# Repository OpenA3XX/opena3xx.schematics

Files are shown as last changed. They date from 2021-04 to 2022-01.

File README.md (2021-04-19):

# OpenA3XX Schematics & PCBs

## OpenA3XX Digital Hardare Controller Board (HCB)
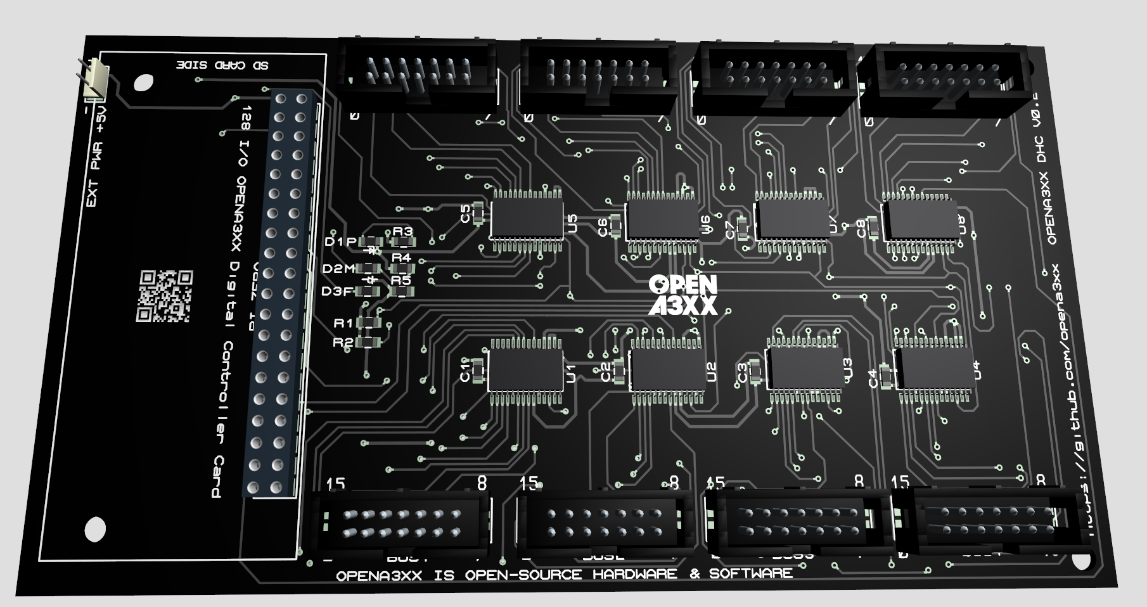
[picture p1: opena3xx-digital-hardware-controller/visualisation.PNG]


## OpenA3XX MCDU with embedded HCB (Optional)
### Front View
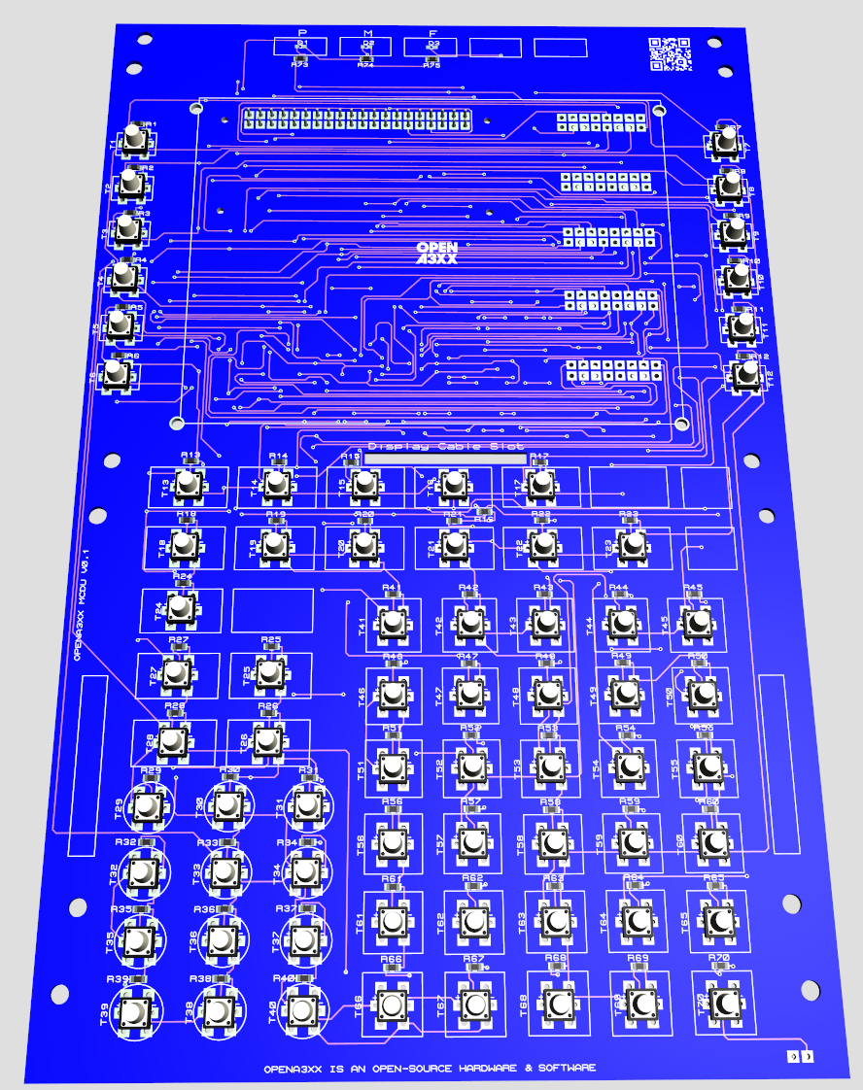
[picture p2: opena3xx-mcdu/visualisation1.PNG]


### Back View
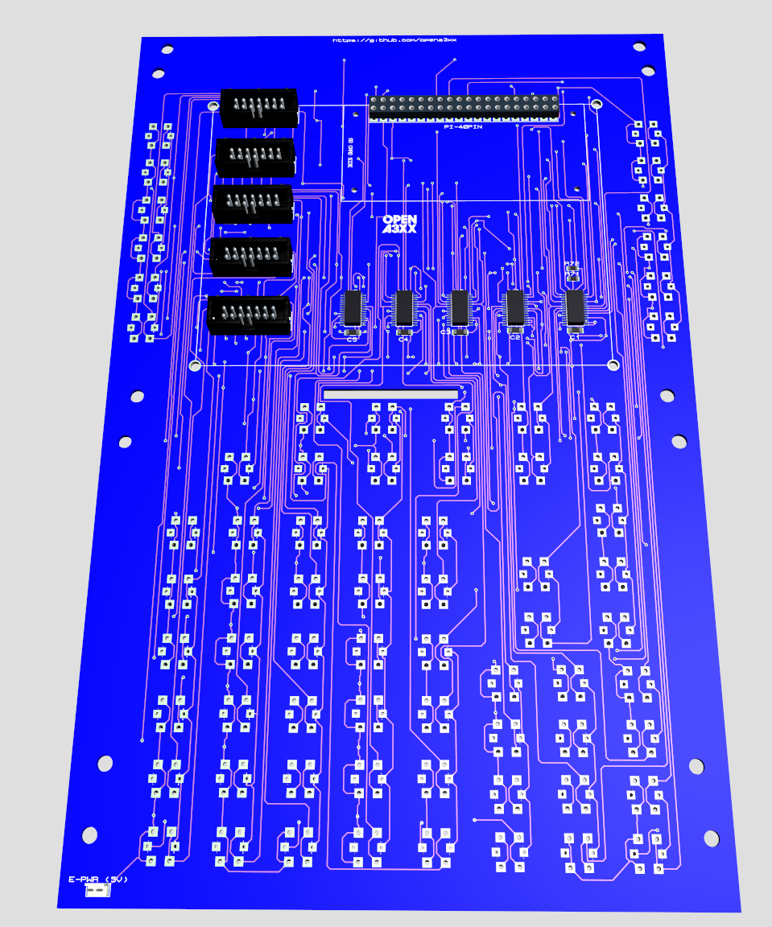
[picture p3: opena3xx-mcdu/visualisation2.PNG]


## OpenA3XX IO Terminal Block Boards

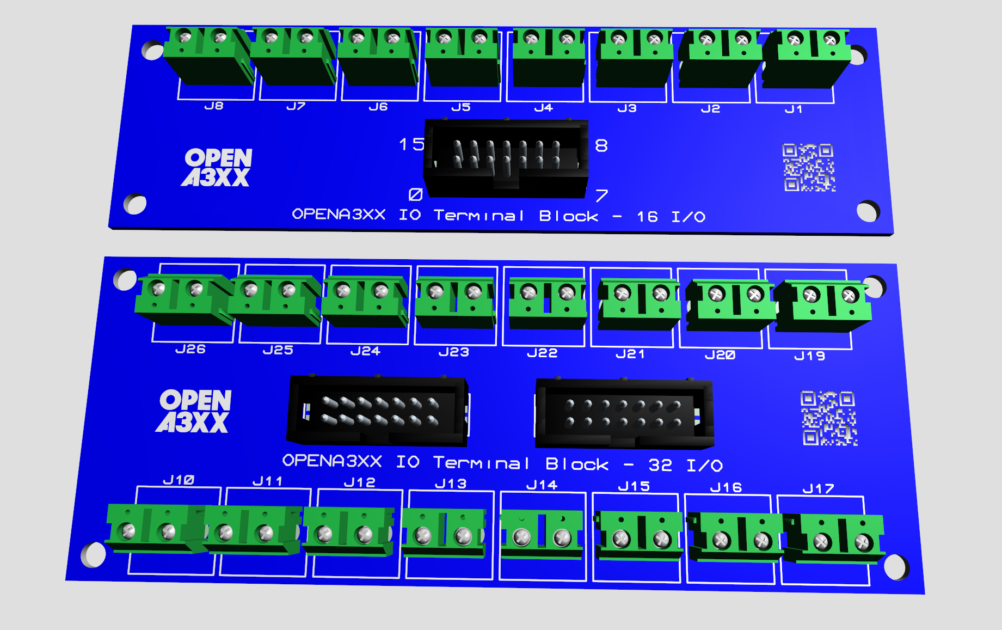
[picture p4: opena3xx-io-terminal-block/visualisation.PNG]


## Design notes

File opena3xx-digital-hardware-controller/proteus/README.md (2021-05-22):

## OpenA3XX Digital Hardware Controller Board

## Design Tools

To open schematics and pcb designs install kicad. Based on your operating system follow the guid here.
[Setup/Download Here](https://www.kicad.org/)

## Versions
- 0.1 (Implemented using Proteus by Labcentre Electronics)
- 0.2 (Implemented using Proteus by Labcentre Electronics)
- 0.3 (Implemented using Proteus by Labcentre Electronics)
- 0.4 (Implemented using Kicad - Open Source)

## Recommendations

For all passive SMD Components it's recommended that you will buy assorted of all values from Aliexpress.
All designs will use footprints which are easy for hand soldering i.e. 1206 package type.
For ICs SOIC packages are used for the same reasons.

## Bill of Material

|Reference|Value |Footprint |Datasheet |
|---|---|---|---|
|U1 |MCP23017_SO |Package_SO:SOIC-28W_7.5x17.9mm_P1.27mm |http://ww1.microchip.com/downloads/en/DeviceDoc/20001952C.pdf |
|BUS0 |Conn_02x08_Counter_Clockwise|Connector_PinHeader_2.54mm:PinHeader_2x08_P2.54mm_Vertical|~ |
|BUS1 |Conn_02x08_Counter_Clockwise|Connector_PinHeader_2.54mm:PinHeader_2x08_P2.54mm_Vertical|~ |
|U2 |MCP23017_SO |Package_SO:SOIC-28W_7.5x17.9mm_P1.27mm |http://ww1.microchip.com/downloads/en/DeviceDoc/20001952C.pdf |
|BUS2 |Conn_02x08_Counter_Clockwise|Connector_PinHeader_2.54mm:PinHeader_2x08_P2.54mm_Vertical|~ |
|U3 |MCP23017_SO |Package_SO:SOIC-28W_7.5x17.9mm_P1.27mm |http://ww1.microchip.com/downloads/en/DeviceDoc/20001952C.pdf |
|J5 |Raspberry_Pi_Zero |Connector_PinHeader_2.54mm:PinHeader_2x20_P2.54mm_Vertical|https://www.raspberrypi.org/documentation/hardware/raspberrypi/schematics/rpi_SCH_3bplus_1p0_reduced.pdf|
|BUS3 |Conn_02x08_Counter_Clockwise|Connector_PinHeader_2.54mm:PinHeader_2x08_P2.54mm_Vertical|~ |
|U4 |MCP23017_SO |Package_SO:SOIC-28W_7.5x17.9mm_P1.27mm |http://ww1.microchip.com/downloads/en/DeviceDoc/20001952C.pdf |
|BUS4 |Conn_02x08_Counter_Clockwise|Connector_PinHeader_2.54mm:PinHeader_2x08_P2.54mm_Vertical|~ |
|U5 |MCP23017_SO |Package_SO:SOIC-28W_7.5x17.9mm_P1.27mm |http://ww1.microchip.com/downloads/en/DeviceDoc/20001952C.pdf |
|BUS5 |Conn_02x08_Counter_Clockwise|Connector_PinHeader_2.54mm:PinHeader_2x08_P2.54mm_Vertical|~ |
|U6 |MCP23017_SO |Package_SO:SOIC-28W_7.5x17.9mm_P1.27mm |http://ww1.microchip.com/downloads/en/DeviceDoc/20001952C.pdf |
|BUS6 |Conn_02x08_Counter_Clockwise|Connector_PinHeader_2.54mm:PinHeader_2x08_P2.54mm_Vertical|~ |
|U7 |MCP23017_SO |Package_SO:SOIC-28W_7.5x17.9mm_P1.27mm |http://ww1.microchip.com/downloads/en/DeviceDoc/20001952C.pdf |
|BUS7 |Conn_02x08_Counter_Clockwise|Connector_PinHeader_2.54mm:PinHeader_2x08_P2.54mm_Vertical|~ |
|U8 |MCP23017_SO |Package_SO:SOIC-28W_7.5x17.9mm_P1.27mm |http://ww1.microchip.com/downloads/en/DeviceDoc/20001952C.pdf |
|D1 |GREEN LED |Diode_SMD:D_1206_3216Metric_Pad1.42x1.75mm_HandSolder |~ |
|R1 |470R |Resistor_SMD:R_1206_3216Metric_Pad1.30x1.75mm_HandSolder  |~ |
|R2 |470R |Resistor_SMD:R_1206_3216Metric_Pad1.30x1.75mm_HandSolder  |~ |
|D3 |RED LED |Diode_SMD:D_1206_3216Metric_Pad1.42x1.75mm_HandSolder |~ |
|R3 |470R |Resistor_SMD:R_1206_3216Metric_Pad1.30x1.75mm_HandSolder  |~ |
|R4 |470R |Resistor_SMD:R_1206_3216Metric_Pad1.30x1.75mm_HandSolder  |~ |
|D4 |ORANGE LED |Diode_SMD:D_1206_3216Metric_Pad1.42x1.75mm_HandSolder |~ |
|D2 |YELLOW LED |Diode_SMD:D_1206_3216Metric_Pad1.42x1.75mm_HandSolder |~ |
|R13 |2.2k |Resistor_SMD:R_1206_3216Metric_Pad1.30x1.75mm_HandSolder  |~ |
|R14 |2.2k |Resistor_SMD:R_1206_3216Metric_Pad1.30x1.75mm_HandSolder  |~ |
|C1 |100n |Capacitor_SMD:C_1206_3216Metric_Pad1.33x1.80mm_HandSolder |~ |
|C2 |100n |Capacitor_SMD:C_1206_3216Metric_Pad1.33x1.80mm_HandSolder |~ |
|C3 |100n |Capacitor_SMD:C_1206_3216Metric_Pad1.33x1.80mm_HandSolder |~ |
|C4 |100n |Capacitor_SMD:C_1206_3216Metric_Pad1.33x1.80mm_HandSolder |~ |
|C5 |100n |Capacitor_SMD:C_1206_3216Metric_Pad1.33x1.80mm_HandSolder |~ |
|C6 |100n |Capacitor_SMD:C_1206_3216Metric_Pad1.33x1.80mm_HandSolder |~ |
|C7 |100n |Capacitor_SMD:C_1206_3216Metric_Pad1.33x1.80mm_HandSolder |~ |
|C8 |100n |Capacitor_SMD:C_1206_3216Metric_Pad1.33x1.80mm_HandSolder |~ |
|R6 |10k |Resistor_SMD:R_1206_3216Metric_Pad1.30x1.75mm_HandSolder  |~ |
|R5 |10k |Resistor_SMD:R_1206_3216Metric_Pad1.30x1.75mm_HandSolder  |~ |
|R7 |10k |Resistor_SMD:R_1206_3216Metric_Pad1.30x1.75mm_HandSolder  |~ |
|R8 |10k |Resistor_SMD:R_1206_3216Metric_Pad1.30x1.75mm_HandSolder  |~ |
|R9 |10k |Resistor_SMD:R_1206_3216Metric_Pad1.30x1.75mm_HandSolder  |~ |
|R10 |10k |Resistor_SMD:R_1206_3216Metric_Pad1.30x1.75mm_HandSolder  |~ |
|R11 |10k |Resistor_SMD:R_1206_3216Metric_Pad1.30x1.75mm_HandSolder  |~ |
|R12 |10k |Resistor_SMD:R_1206_3216Metric_Pad1.30x1.75mm_HandSolder  |~ |
|J1 |Conn_02x01 |Connector_PinHeader_2.54mm:PinHeader_1x02_P2.54mm_Vertical|~ |
|J2 |Conn_02x01 |Connector_PinHeader_2.54mm:PinHeader_1x02_P2.54mm_Vertical|~ |
|J3 |Conn_02x01 |TerminalBlock:TerminalBlock_bornier-2_P5.08mm |~ |
|J4 |Conn_02x01 |TerminalBlock:TerminalBlock_bornier-2_P5.08mm |~ |
|SW1 |SW_MEC_5E |Button_Switch_THT:SW_Tactile_Straight_KSL0Axx1LFTR |http://www.apem.com/int/index.php?controller=attachment&id_attachment=1371 |
|R15 |2.2k |Resistor_SMD:R_1206_3216Metric_Pad1.30x1.75mm_HandSolder  |~ |

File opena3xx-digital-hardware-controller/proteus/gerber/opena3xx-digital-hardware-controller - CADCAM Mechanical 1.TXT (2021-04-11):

G04 PROTEUS RS274X GERBER FILE*
%FSLAX24Y24*%
%MOIN*%
%ADD15C,0.0080*%
G54D15*
X-50787Y+29527D02*
X-16535Y+29527D01*
X-16535Y+48031D01*
X-50787Y+48031D01*
X-50787Y+29527D01*
M00*

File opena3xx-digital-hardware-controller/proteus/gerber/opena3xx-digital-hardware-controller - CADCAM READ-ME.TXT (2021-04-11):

LABCENTER PROTEUS TOOL INFORMATION FILE
=======================================

In case of difficulty, please e-mail support@labcenter.co.uk

Tool set up for Proteus layout 'opena3xx-digital-hardware-controller.LYT'.
CADCAM generated at 22:12:48 on 10 April 2021.

File List
---------
Top Copper              : opena3xx-digital-hardware-controller - CADCAM Top Copper.TXT
Bottom Copper           : opena3xx-digital-hardware-controller - CADCAM Bottom Copper.TXT
Top Silk Screen         : opena3xx-digital-hardware-controller - CADCAM Top Silk Screen.TXT
Top Solder Resist       : opena3xx-digital-hardware-controller - CADCAM Top Solder Resist.TXT
Bottom Solder Resist    : opena3xx-digital-hardware-controller - CADCAM Bottom Solder Resist.TXT
Top SMT Paste Mask      : opena3xx-digital-hardware-controller - CADCAM Top SMT Paste Mask.TXT
Mechanical 1            : opena3xx-digital-hardware-controller - CADCAM Mechanical 1.TXT
Drill                   : opena3xx-digital-hardware-controller - CADCAM Drill.TXT

Photoplotter Setup
------------------
Format: RS274X, ASCII, 2.4, imperial, absolute, eob=*, LZO
Notes:  D=Diameter, S=Side, W=Width, H=Height, C=Chamfer

D10	CIRCLE  D=10th                                                            DRAW
D11	CIRCLE  D=30th                                                            FLASH
D12	SQUARE  S=80th                                                            FLASH
D13	RECT    W=39.3th              H=11.8th                                    FLASH
D14	RECT    W=40th                H=50th                                      FLASH
D15	CIRCLE  D=8th                                                             DRAW
D16	CIRCLE  D=50th                                                            FLASH
D17	SQUARE  S=100th                                                           FLASH
D18	RECT    W=59.3th              H=31.8th                                    FLASH
D19	RECT    W=60th                H=70th                                      FLASH

NC Drill Setup
--------------
Format: ASCII, 2.4, imperial, absolute, eob=<CR><LF>, no zero suppression.
Notes:  Tool sizes are diameters. Layer sets are in brackets - 0=TOP, 15=BOTTOM, 1-14=INNER.

T01	15th (0-15)
T02	40th (0-15)
T03	30th (0-15)

[END OF FILE]

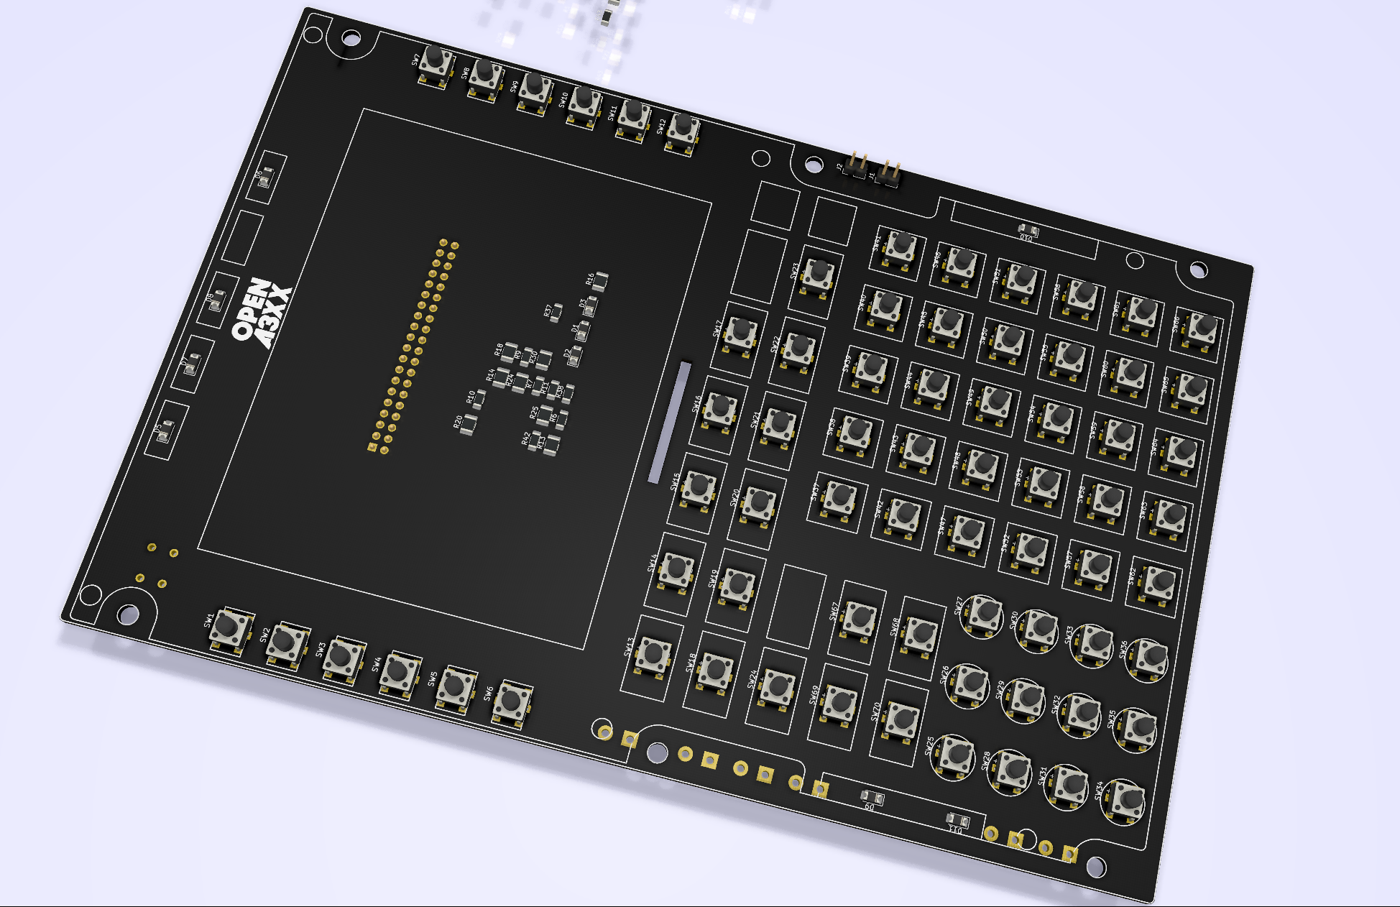
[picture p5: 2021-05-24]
opena3xx-mcdu/proteus/MCDU_Render3.png

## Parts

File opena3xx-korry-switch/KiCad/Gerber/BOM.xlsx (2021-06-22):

Comment | Designator | Footprint | LCSC Part #（optional）
270 | R1 | R_1206_3216Metric
270 | R2 | R_1206_3216Metric
1x5 2.54mm Vertical | CON1 | Conn_01x05_MountingPin

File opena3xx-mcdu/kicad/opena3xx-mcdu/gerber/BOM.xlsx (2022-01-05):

Comment | Designator | Footprint | LCSC Part #（optional）
Terminal Block | J1 | Conn_02x01_TerminalBlock | C8404
Terminal Block | J2 | Conn_02x01_TerminalBlock | C8404
Terminal Block | J3 | Conn_02x01_TerminalBlock | C8404
Terminal Block | J4 | Conn_02x01_TerminalBlock | C8404
Terminal Block | J6 | Conn_02x01_TerminalBlock | C8404
Terminal Block | J7 | Conn_02x01_TerminalBlock | C8404
Terminal Block | J8 | Conn_02x01_TerminalBlock | C8404
Terminal Block | J9 | Conn_02x01_TerminalBlock | C8404
Tactile Switch with LED | SW1 | TLL-6A_TACTILE_LED_TH | C354965
Tactile Switch with LED | SW2 | TLL-6A_TACTILE_LED_TH | C354965
Tactile Switch with LED | SW3 | TLL-6A_TACTILE_LED_TH | C354965
Tactile Switch with LED | SW4 | TLL-6A_TACTILE_LED_TH | C354965
Tactile Switch with LED | SW5 | TLL-6A_TACTILE_LED_TH | C354965
Tactile Switch with LED | SW6 | TLL-6A_TACTILE_LED_TH | C354965
Tactile Switch with LED | SW7 | TLL-6A_TACTILE_LED_TH | C354965
Tactile Switch with LED | SW8 | TLL-6A_TACTILE_LED_TH | C354965
Tactile Switch with LED | SW9 | TLL-6A_TACTILE_LED_TH | C354965
Tactile Switch with LED | SW10 | TLL-6A_TACTILE_LED_TH | C354965
Tactile Switch with LED | SW11 | TLL-6A_TACTILE_LED_TH | C354965
Tactile Switch with LED | SW12 | TLL-6A_TACTILE_LED_TH | C354965
Tactile Switch with LED | SW13 | TLL-6A_TACTILE_LED_TH | C354965
Tactile Switch with LED | SW14 | TLL-6A_TACTILE_LED_TH | C354965
Tactile Switch with LED | SW15 | TLL-6A_TACTILE_LED_TH | C354965
Tactile Switch with LED | SW16 | TLL-6A_TACTILE_LED_TH | C354965
Tactile Switch with LED | SW17 | TLL-6A_TACTILE_LED_TH | C354965
Tactile Switch with LED | SW18 | TLL-6A_TACTILE_LED_TH | C354965
Tactile Switch with LED | SW19 | TLL-6A_TACTILE_LED_TH | C354965
Tactile Switch with LED | SW20 | TLL-6A_TACTILE_LED_TH | C354965
Tactile Switch with LED | SW21 | TLL-6A_TACTILE_LED_TH | C354965
Tactile Switch with LED | SW22 | TLL-6A_TACTILE_LED_TH | C354965
Tactile Switch with LED | SW23 | TLL-6A_TACTILE_LED_TH | C354965
Tactile Switch with LED | SW24 | TLL-6A_TACTILE_LED_TH | C354965
Tactile Switch with LED | SW25 | TLL-6A_TACTILE_LED_TH | C354965
Tactile Switch with LED | SW26 | TLL-6A_TACTILE_LED_TH | C354965
Tactile Switch with LED | SW27 | TLL-6A_TACTILE_LED_TH | C354965
Tactile Switch with LED | SW28 | TLL-6A_TACTILE_LED_TH | C354965
Tactile Switch with LED | SW29 | TLL-6A_TACTILE_LED_TH | C354965
Tactile Switch with LED | SW30 | TLL-6A_TACTILE_LED_TH | C354965
Tactile Switch with LED | SW31 | TLL-6A_TACTILE_LED_TH | C354965
Tactile Switch with LED | SW32 | TLL-6A_TACTILE_LED_TH | C354965
Tactile Switch with LED | SW33 | TLL-6A_TACTILE_LED_TH | C354965
Tactile Switch with LED | SW34 | TLL-6A_TACTILE_LED_TH | C354965
Tactile Switch with LED | SW35 | TLL-6A_TACTILE_LED_TH | C354965
Tactile Switch with LED | SW36 | TLL-6A_TACTILE_LED_TH | C354965
Tactile Switch with LED | SW37 | TLL-6A_TACTILE_LED_TH | C354965
Tactile Switch with LED | SW38 | TLL-6A_TACTILE_LED_TH | C354965
Tactile Switch with LED | SW39 | TLL-6A_TACTILE_LED_TH | C354965
Tactile Switch with LED | SW40 | TLL-6A_TACTILE_LED_TH | C354965
Tactile Switch with LED | SW41 | TLL-6A_TACTILE_LED_TH | C354965
Tactile Switch with LED | SW42 | TLL-6A_TACTILE_LED_TH | C354965
Tactile Switch with LED | SW43 | TLL-6A_TACTILE_LED_TH | C354965
Tactile Switch with LED | SW44 | TLL-6A_TACTILE_LED_TH | C354965
Tactile Switch with LED | SW45 | TLL-6A_TACTILE_LED_TH | C354965
Tactile Switch with LED | SW46 | TLL-6A_TACTILE_LED_TH | C354965
Tactile Switch with LED | SW47 | TLL-6A_TACTILE_LED_TH | C354965
Tactile Switch with LED | SW48 | TLL-6A_TACTILE_LED_TH | C354965
Tactile Switch with LED | SW49 | TLL-6A_TACTILE_LED_TH | C354965
Tactile Switch with LED | SW50 | TLL-6A_TACTILE_LED_TH | C354965
Tactile Switch with LED | SW51 | TLL-6A_TACTILE_LED_TH | C354965
Tactile Switch with LED | SW52 | TLL-6A_TACTILE_LED_TH | C354965
Tactile Switch with LED | SW53 | TLL-6A_TACTILE_LED_TH | C354965
Tactile Switch with LED | SW54 | TLL-6A_TACTILE_LED_TH | C354965
Tactile Switch with LED | SW55 | TLL-6A_TACTILE_LED_TH | C354965
Tactile Switch with LED | SW56 | TLL-6A_TACTILE_LED_TH | C354965
Tactile Switch with LED | SW57 | TLL-6A_TACTILE_LED_TH | C354965
Tactile Switch with LED | SW58 | TLL-6A_TACTILE_LED_TH | C354965
Tactile Switch with LED | SW59 | TLL-6A_TACTILE_LED_TH | C354965
Tactile Switch with LED | SW60 | TLL-6A_TACTILE_LED_TH | C354965
Tactile Switch with LED | SW61 | TLL-6A_TACTILE_LED_TH | C354965
Tactile Switch with LED | SW62 | TLL-6A_TACTILE_LED_TH | C354965
Tactile Switch with LED | SW63 | TLL-6A_TACTILE_LED_TH | C354965
Tactile Switch with LED | SW64 | TLL-6A_TACTILE_LED_TH | C354965
Tactile Switch with LED | SW65 | TLL-6A_TACTILE_LED_TH | C354965
Tactile Switch with LED | SW66 | TLL-6A_TACTILE_LED_TH | C354965
Tactile Switch with LED | SW67 | TLL-6A_TACTILE_LED_TH | C354965
Tactile Switch with LED | SW68 | TLL-6A_TACTILE_LED_TH | C354965
Tactile Switch with LED | SW69 | TLL-6A_TACTILE_LED_TH | C354965
Tactile Switch with LED | SW70 | TLL-6A_TACTILE_LED_TH | C354965
Tactile Switch with LED | SW71 | TLL-6A_TACTILE_LED_TH | C354965
Tactile Switch with LED | SW72 | TLL-6A_TACTILE_LED_TH | C354965
Tactile Switch with LED | SW73 | TLL-6A_TACTILE_LED_TH | C354965
Tactile Switch with LED | SW74 | TLL-6A_TACTILE_LED_TH | C354965
220R | R13 | R_1210_3225Metric | C17957
220R | R14 | R_1210_3225Metric | C17957
220R | R15 | R_1210_3225Metric | C17957
220R | R16 | R_1210_3225Metric | C17957
220R | R17 | R_1210_3225Metric | C17957
220R | R18 | R_1210_3225Metric | C17957
220R | R19 | R_1210_3225Metric | C17957
220R | R20 | R_1210_3225Metric | C17957
220R | R21 | R_1210_3225Metric | C17957
220R | R22 | R_1210_3225Metric | C17957
220R | R23 | R_1210_3225Metric | C17957
220R | R24 | R_1210_3225Metric | C17957
220R | R25 | R_1210_3225Metric | C17957
220R | R26 | R_1210_3225Metric | C17957
220R | R27 | R_1210_3225Metric | C17957
220R | R28 | R_1210_3225Metric | C17957
220R | R29 | R_1210_3225Metric | C17957
220R | R30 | R_1210_3225Metric | C17957
220R | R31 | R_1210_3225Metric | C17957
220R | R32 | R_1210_3225Metric | C17957
220R | R33 | R_1210_3225Metric | C17957
220R | R34 | R_1210_3225Metric | C17957
220R | R35 | R_1210_3225Metric | C17957
220R | R44 | R_1210_3225Metric | C17957
MCP23017_SO | U1 | SOIC-28W | C47023
MCP23017_SO | U2 | SOIC-28W | C47023
MCP23017_SO | U3 | SOIC-28W | C47023
MCP23017_SO | U4 | SOIC-28W | C47023
MCP23017_SO | U5 | SOIC-28W | C47023
Tactile Switch MEC_5E | SW100 | SW_TH_Tactile_Omron_B3F-10xx | C111609
470R | R43 | R_1206_3216Metric | C4502
470R | R42 | R_1206_3216Metric | C4502
470R | R41 | R_1206_3216Metric | C4502
470R | R40 | R_1206_3216Metric | C4502
470R | R39 | R_1206_3216Metric | C4502
470R | R38 | R_1206_3216Metric | C4502
470R | R37 | R_1206_3216Metric | C4502
470R | R4 | R_1206_3216Metric | C4502
470R | R3 | R_1206_3216Metric | C4502
470R | R2 | R_1206_3216Metric | C4502
470R | R36 | R_1206_3216Metric | C4502
470R | R1 | R_1206_3216Metric | C4502
2.2K | R12 | R_1206_3216Metric | C17948
2.2K | R11 | R_1206_3216Metric | C17948
2.2K | R10 | R_1206_3216Metric | C17948
10K | R9 | R_1206_3216Metric | C17902
10K | R8 | R_1206_3216Metric | C17902
10K | R7 | R_1206_3216Metric | C17902
10K | R6 | R_1206_3216Metric | C17902
10K | R5 | R_1206_3216Metric | C17902
2x20 2.54mm Vertical | J5 | Conn_02x20_MountingPin | C124383
White LED | D11 | D_1206_3216Metric | C130718
White LED | D10 | D_1206_3216Metric | C130718
Amber LED | D9 | D_1206_3216Metric | C93094
Green LED | D8 | D_1206_3216Metric | C434439
Amber LED | D7 | D_1206_3216Metric | C93094
Amber LED | D6 | D_1206_3216Metric | C93094
Amber LED | D5 | D_1206_3216Metric | C93094
Orange LED | D4 | D_1206_3216Metric | C93094
Red LED | D3 | D_1206_3216Metric | C192674
Yellow LED | D2 | D_1206_3216Metric | C93094
Green LED | D1 | D_1206_3216Metric | C434439
100n Capacitor | C1 | C_1206_3216Metric | C24497
100n Capacitor | C2 | C_1206_3216Metric | C24497
100n Capacitor | C3 | C_1206_3216Metric | C24497
100n Capacitor | C4 | C_1206_3216Metric | C24497
100n Capacitor | C5 | C_1206_3216Metric | C24497
22.0K | R45 | R_1206_3216Metric | C25830
10.0K | R46 | R_1206_3216Metric | C17902
220R | R47 | R_1206_3216Metric | C17957

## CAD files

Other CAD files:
opena3xx-mcdu/proteus/1212D.dwg

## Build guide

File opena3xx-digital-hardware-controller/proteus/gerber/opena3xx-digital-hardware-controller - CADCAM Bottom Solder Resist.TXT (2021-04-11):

G04 PROTEUS RS274X GERBER FILE*
%FSLAX24Y24*%
%MOIN*%
%ADD16C,0.0500*%
%ADD17R,0.1000X0.1000*%
%ADD15C,0.0080*%
G54D16*
X-33250Y+34500D03*
X-46250Y+36000D03*
X-43000Y+35750D03*
X-41750Y+30500D03*
X-43000Y+35250D03*
X-44000Y+35250D03*
X-46250Y+31000D03*
X-33250Y+30500D03*
X-37500Y+30500D03*
X-48500Y+42750D03*
X-38750Y+31000D03*
X-32500Y+36500D03*
X-35250Y+32000D03*
X-41750Y+31000D03*
X-37500Y+36250D03*
X-46250Y+36500D03*
X-34250Y+35250D03*
X-40750Y+30250D03*
X-37000Y+31000D03*
X-30250Y+36250D03*
X-24750Y+39250D03*
X-23750Y+39500D03*
X-21750Y+40000D03*
X-19750Y+41000D03*
X-18750Y+42250D03*
X-31500Y+35750D03*
X-40500Y+35500D03*
X-41250Y+37250D03*
X-36500Y+30750D03*
X-47750Y+45000D03*
X-36500Y+37000D03*
X-31000Y+31000D03*
X-29750Y+31000D03*
X-31500Y+36750D03*
X-31500Y+36250D03*
X-41750Y+36500D03*
X-41750Y+34000D03*
G54D17*
X-46850Y+45669D03*
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

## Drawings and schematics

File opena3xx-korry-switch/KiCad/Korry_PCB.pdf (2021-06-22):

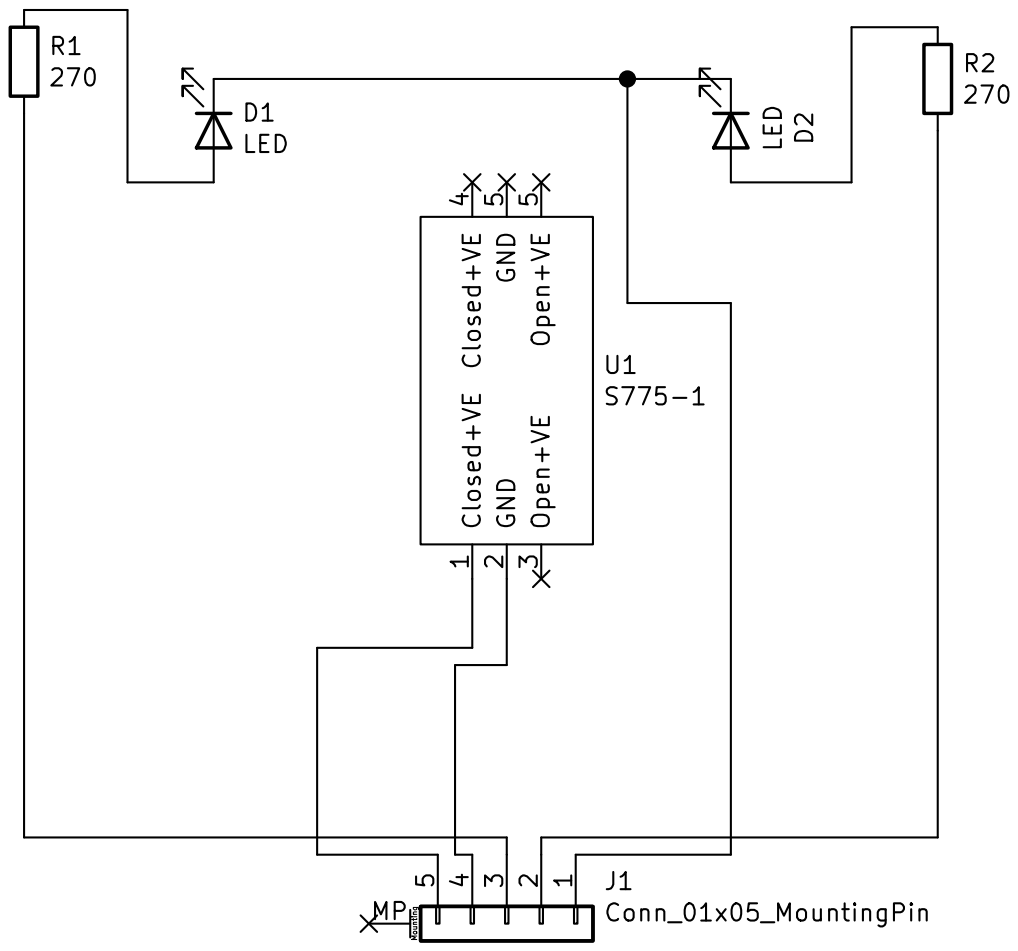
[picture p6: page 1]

Id: 1/1 Title: Korry Switch PCB

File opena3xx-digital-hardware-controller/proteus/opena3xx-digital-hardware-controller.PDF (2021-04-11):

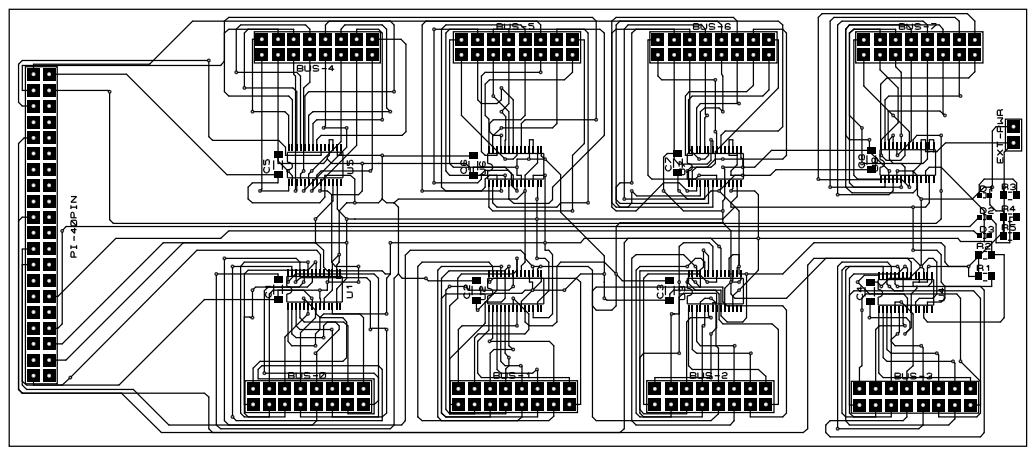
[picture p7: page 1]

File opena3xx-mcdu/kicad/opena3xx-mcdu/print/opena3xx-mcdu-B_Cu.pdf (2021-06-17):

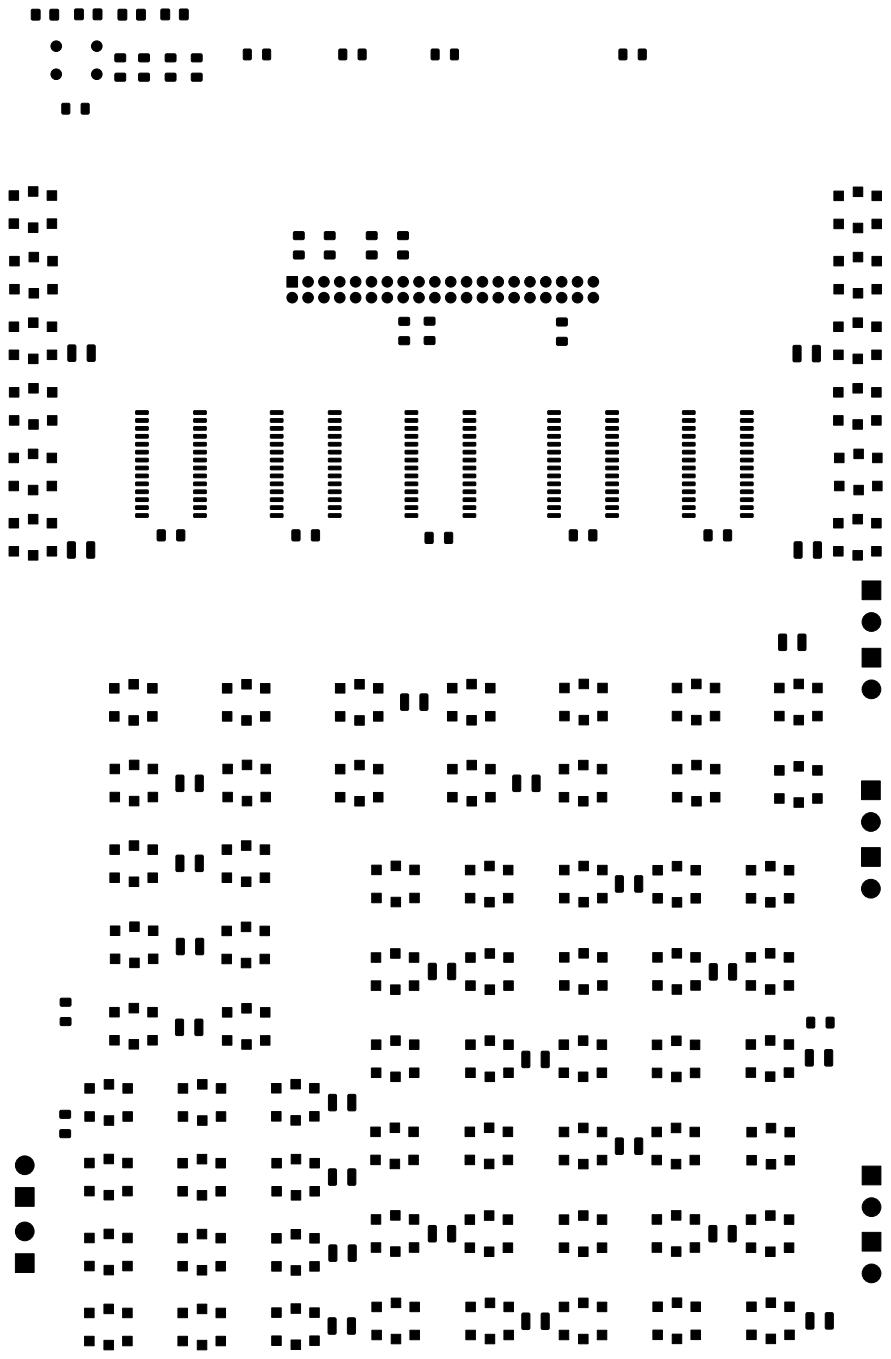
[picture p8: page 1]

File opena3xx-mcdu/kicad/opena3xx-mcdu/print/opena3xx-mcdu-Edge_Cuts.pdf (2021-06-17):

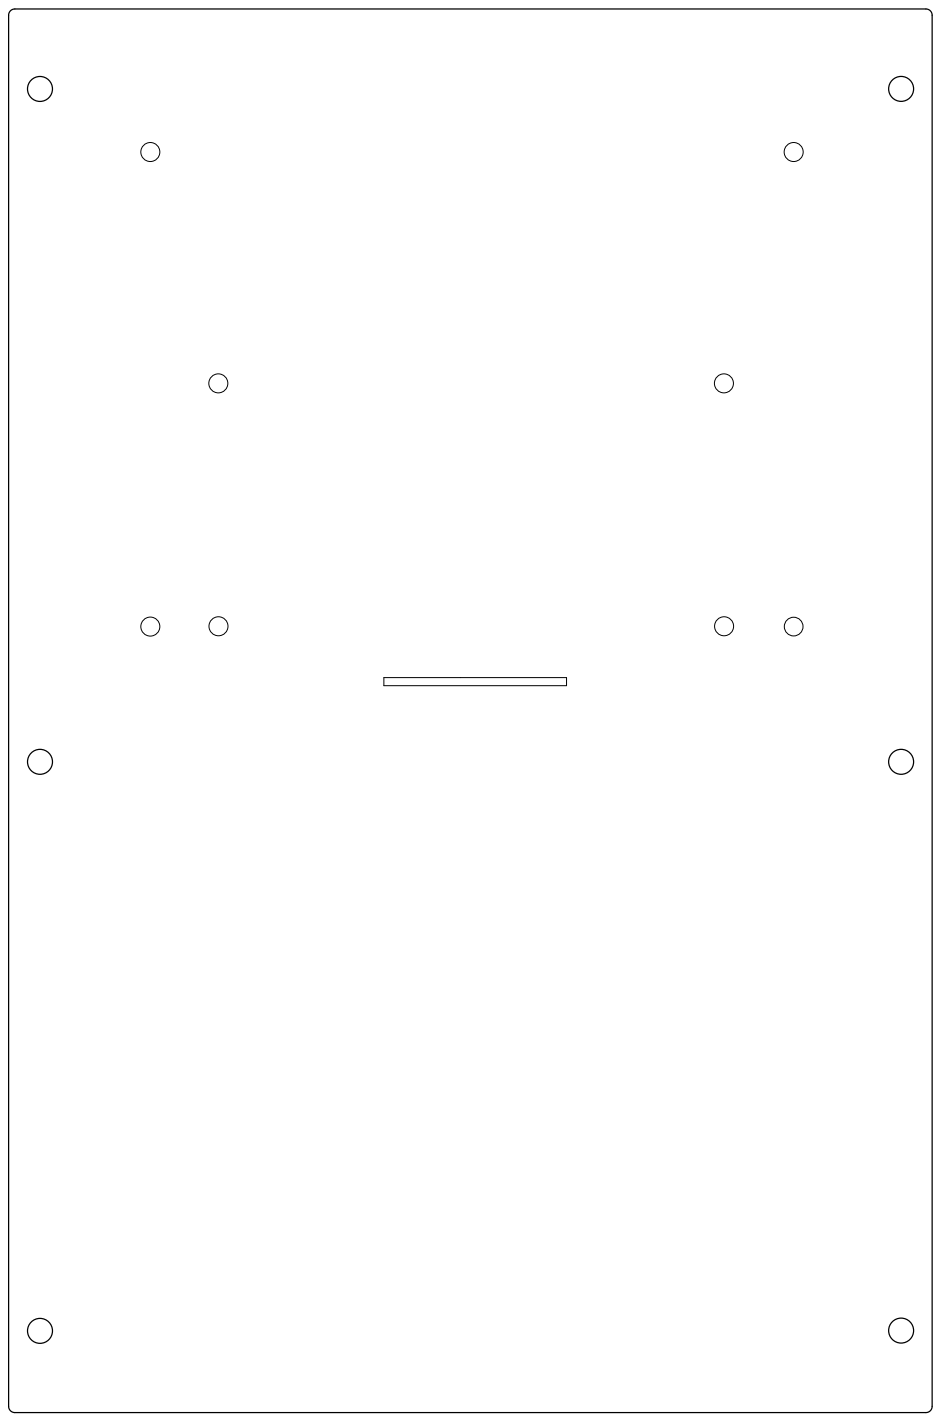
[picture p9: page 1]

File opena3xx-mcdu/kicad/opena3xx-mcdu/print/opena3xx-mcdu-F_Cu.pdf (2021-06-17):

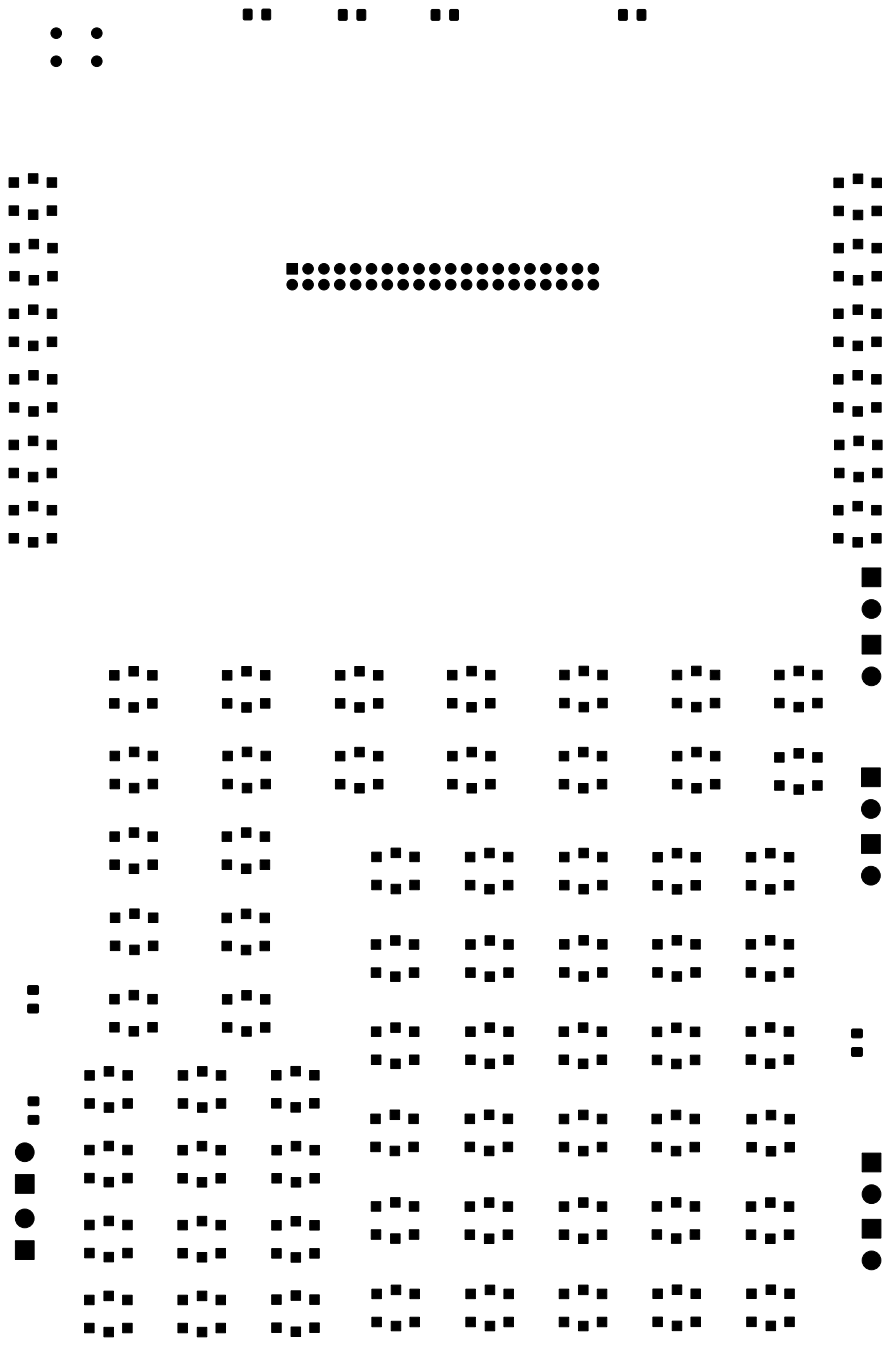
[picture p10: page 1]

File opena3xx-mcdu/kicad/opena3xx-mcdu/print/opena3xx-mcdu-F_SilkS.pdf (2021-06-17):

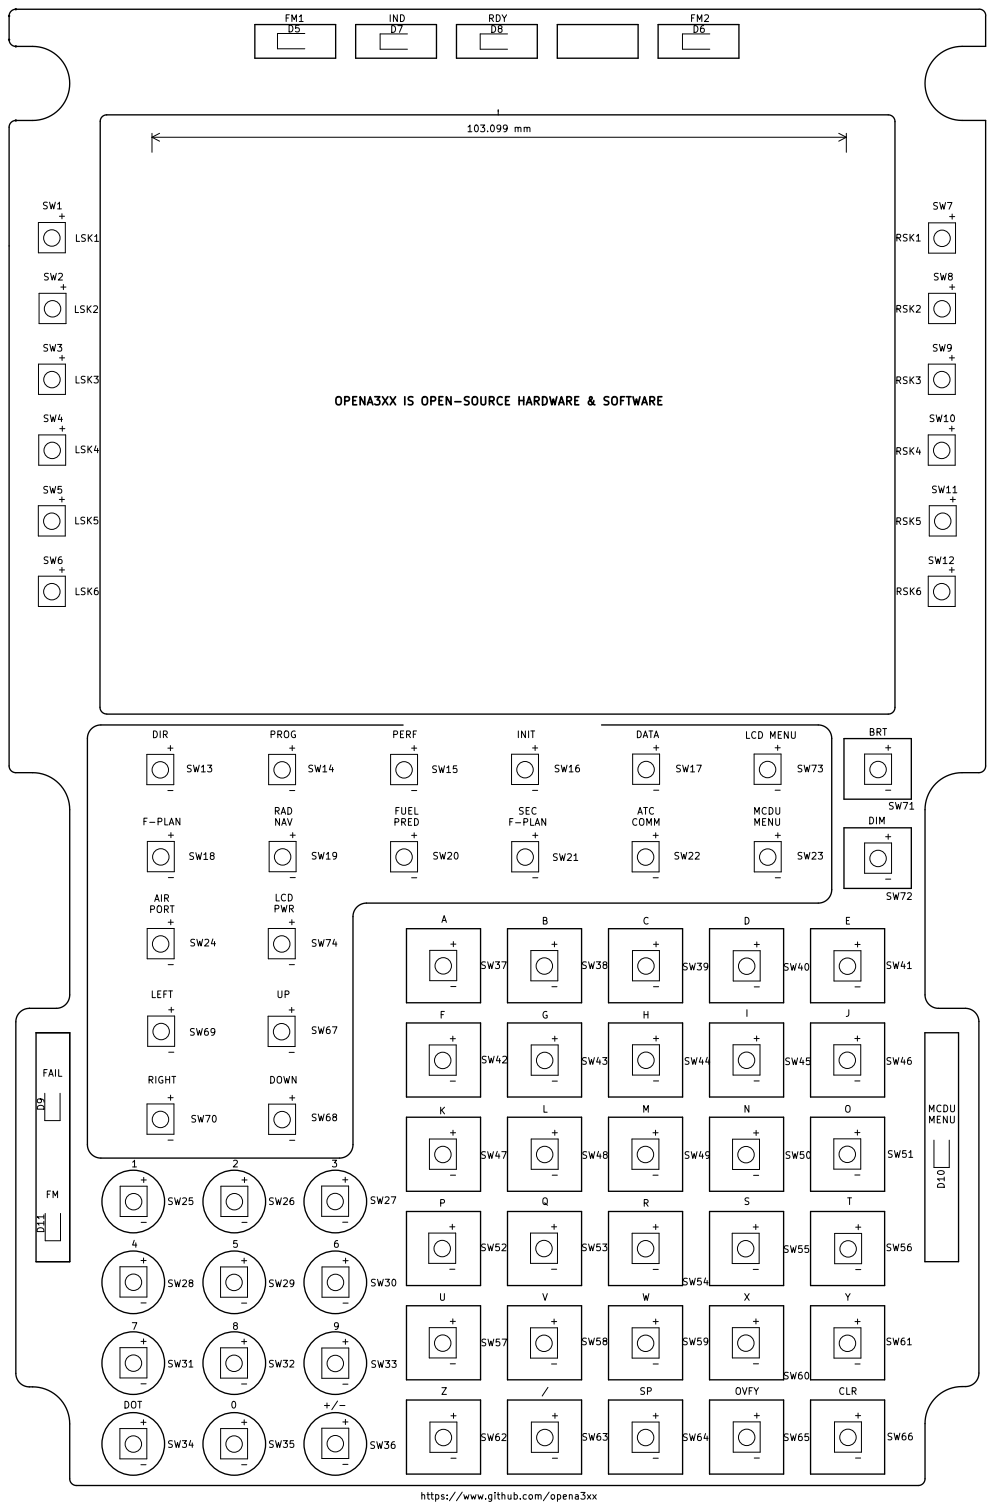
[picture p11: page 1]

https://www.github.com/opena3xx

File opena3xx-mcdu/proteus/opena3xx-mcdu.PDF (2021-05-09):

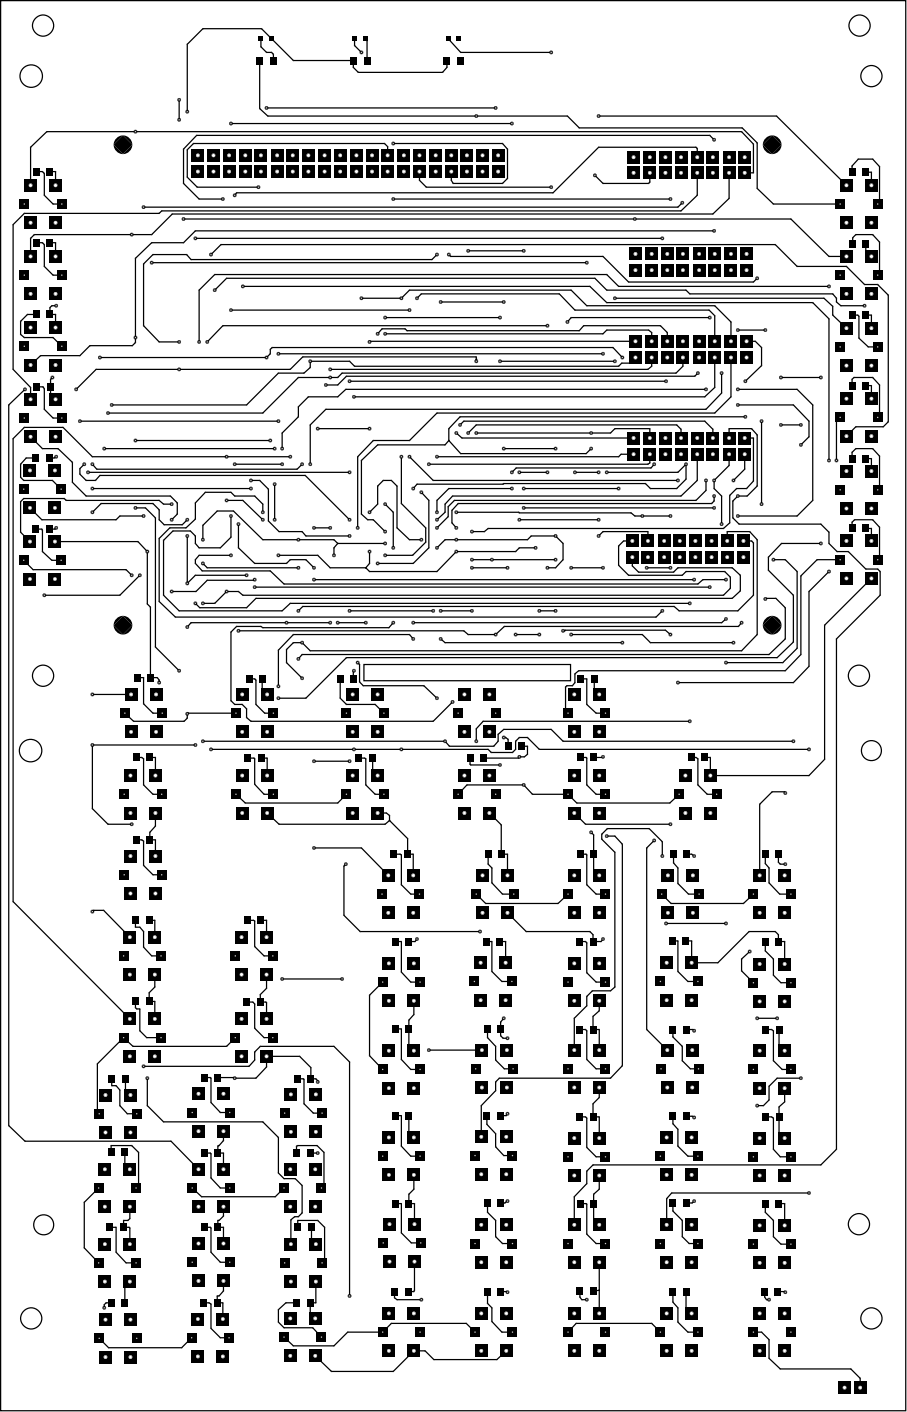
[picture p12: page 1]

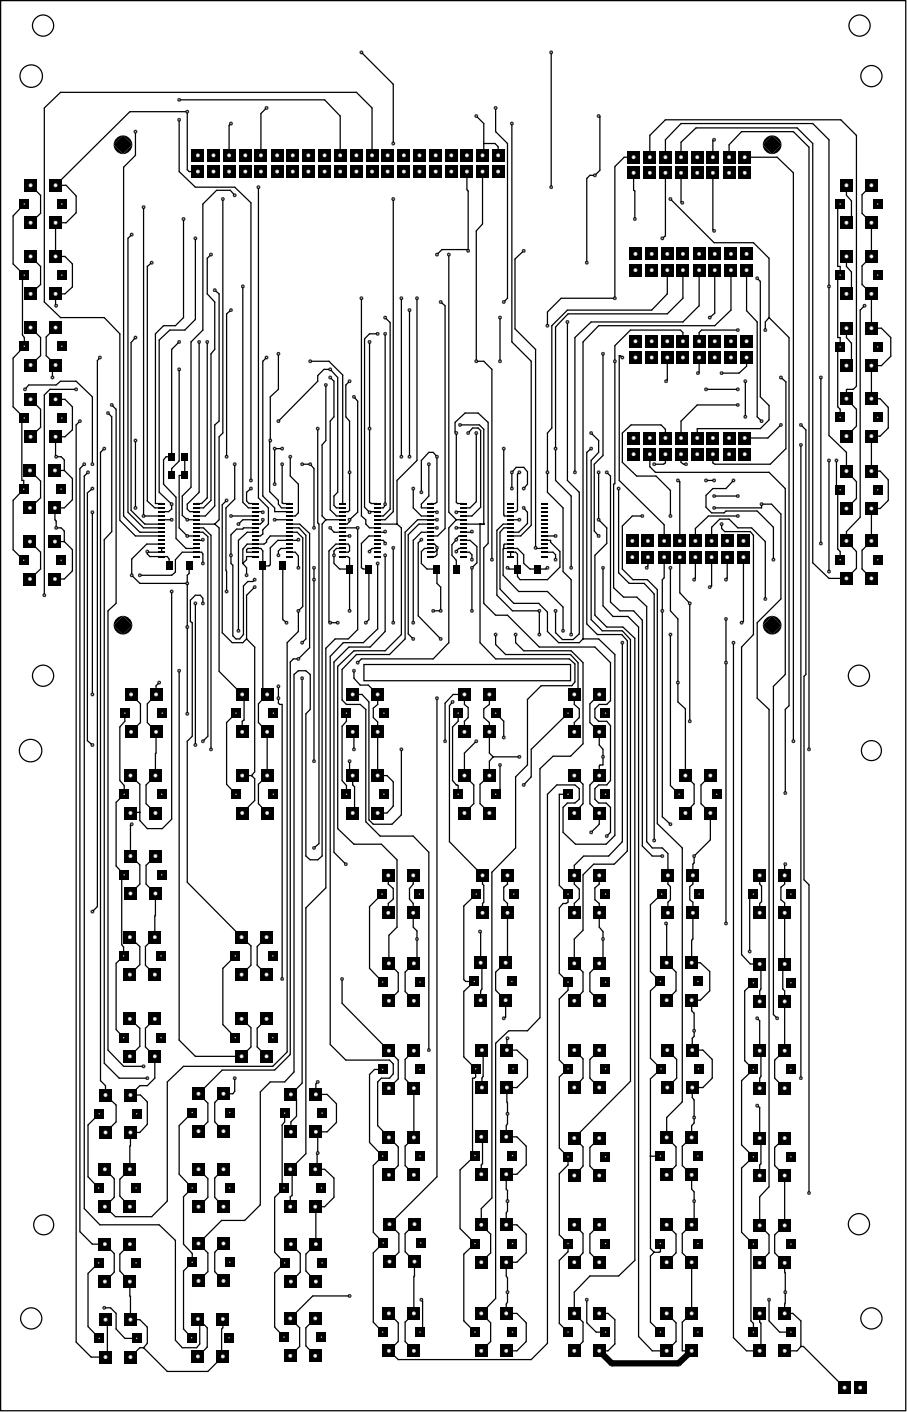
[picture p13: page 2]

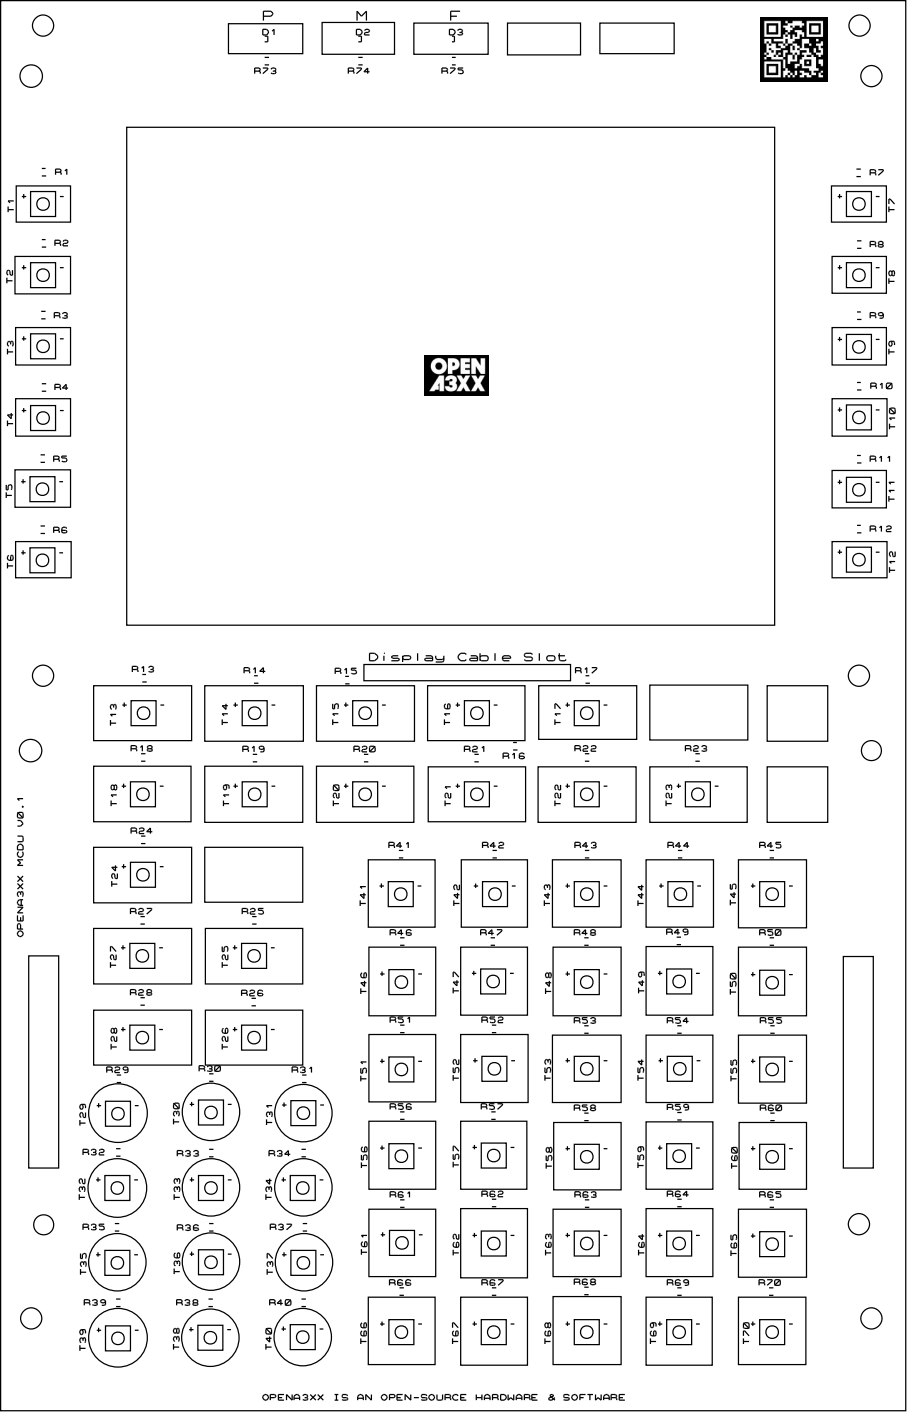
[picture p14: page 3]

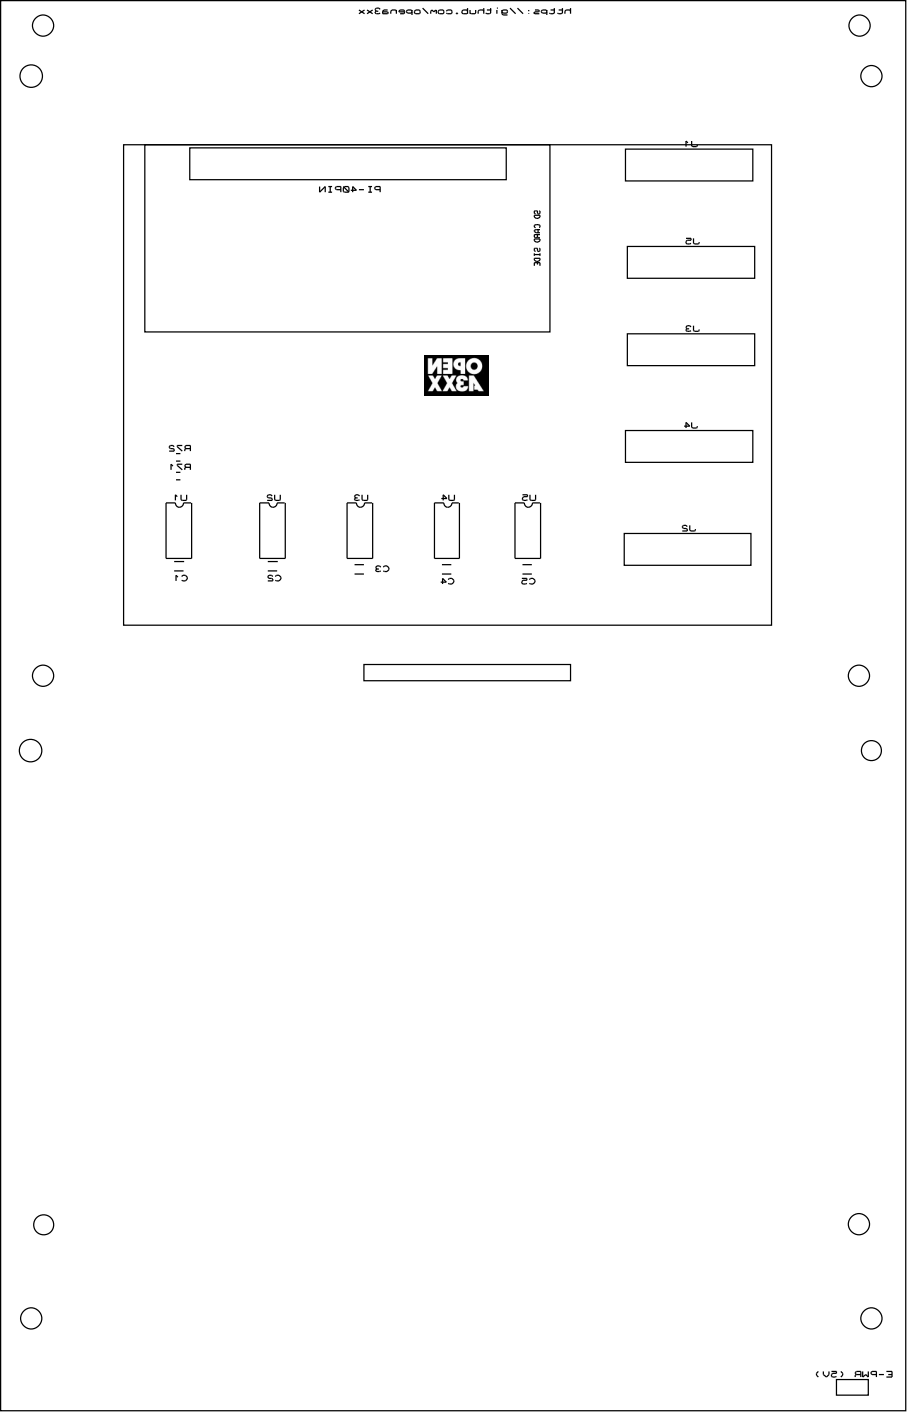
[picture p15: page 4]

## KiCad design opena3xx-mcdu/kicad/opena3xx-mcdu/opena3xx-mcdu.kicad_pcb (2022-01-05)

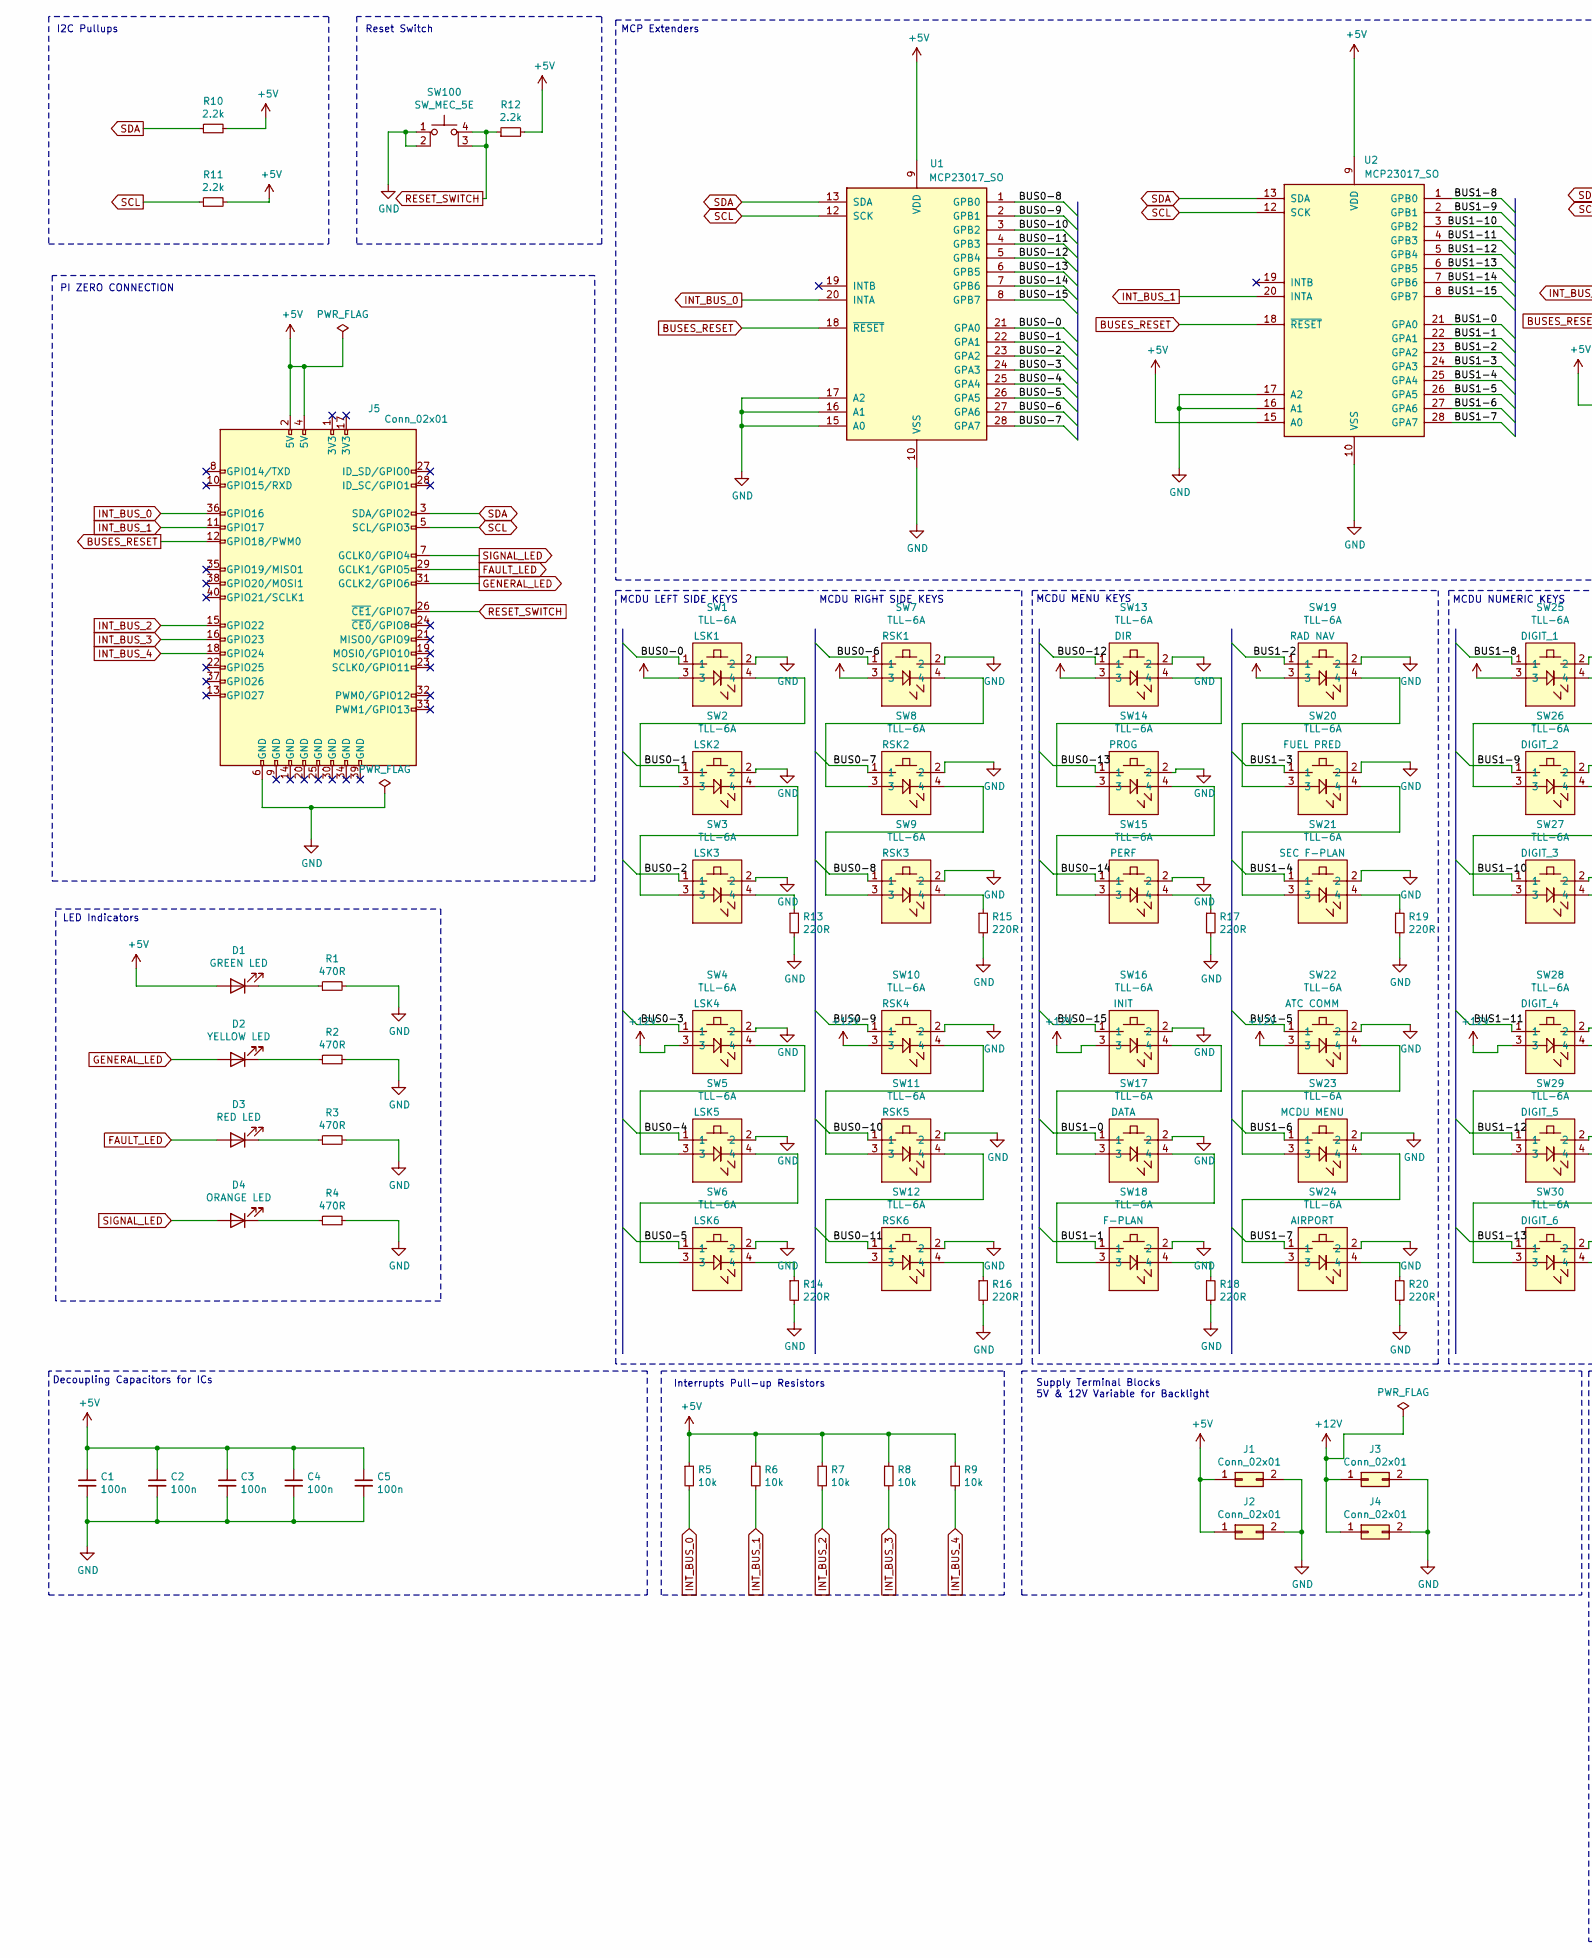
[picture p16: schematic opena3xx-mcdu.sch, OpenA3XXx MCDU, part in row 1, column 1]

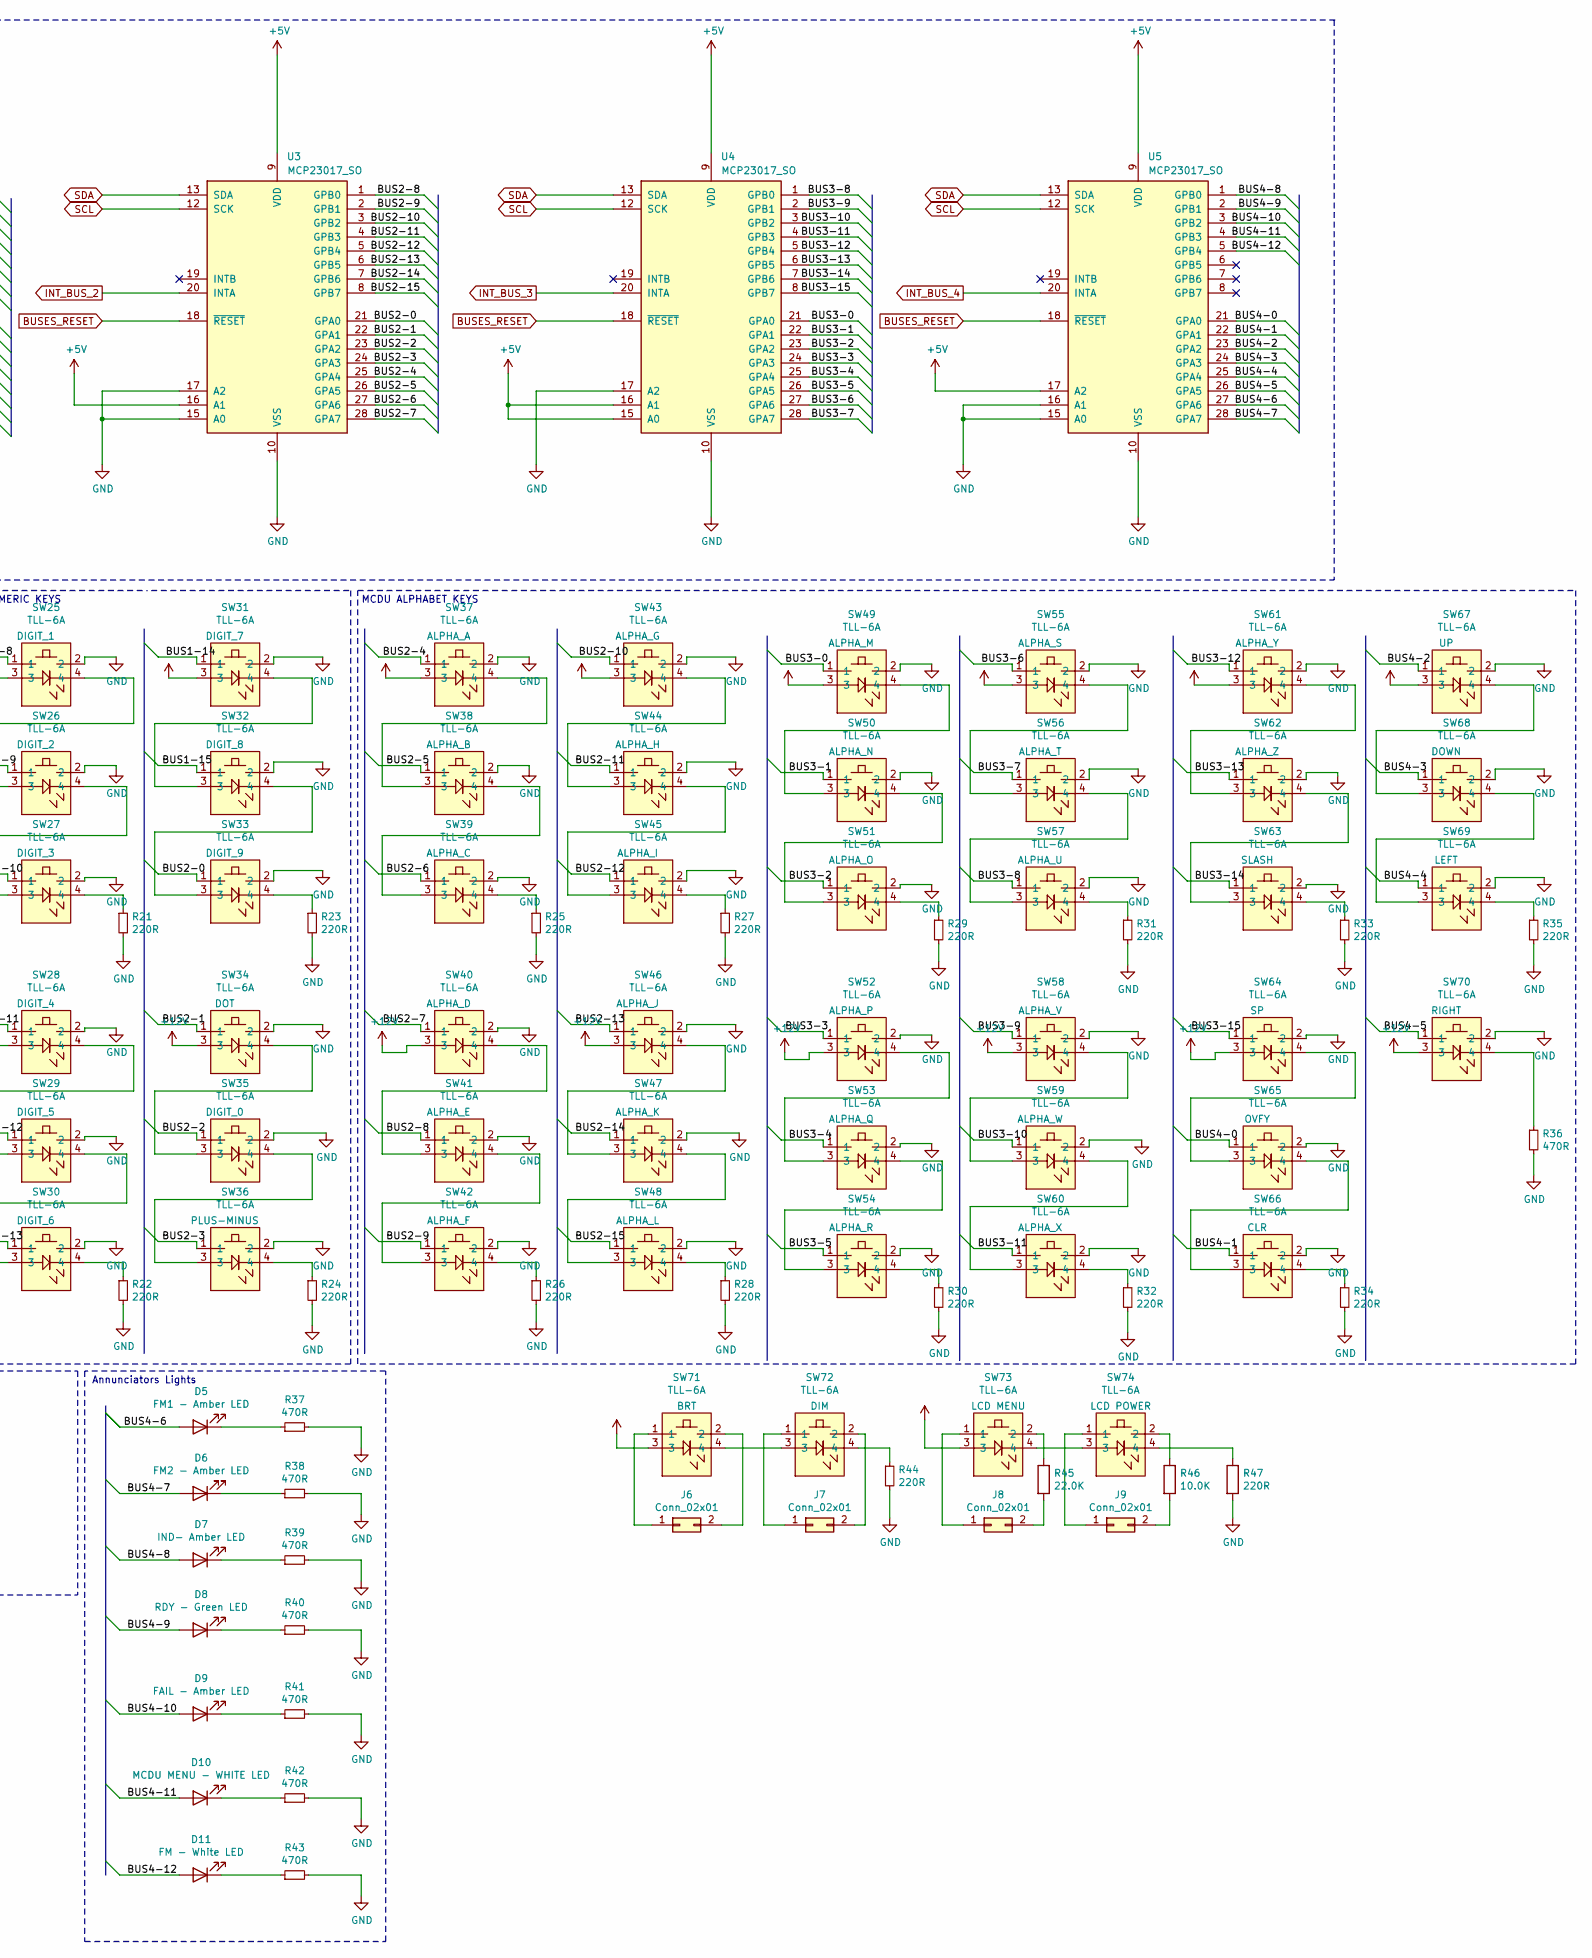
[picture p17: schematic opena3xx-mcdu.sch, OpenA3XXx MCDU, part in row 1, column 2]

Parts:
C1, C2, C3, C4, C5: 100n; C_1206_3216Metric_Pad1.33x1.80mm_HandSolder
D1: GREEN LED; D_1206_3216Metric_Pad1.42x1.75mm_HandSolder
D2: YELLOW LED; D_1206_3216Metric_Pad1.42x1.75mm_HandSolder
D3: RED LED; D_1206_3216Metric_Pad1.42x1.75mm_HandSolder
D4: ORANGE LED; D_1206_3216Metric_Pad1.42x1.75mm_HandSolder
D5: FM1 - Amber LED; D_1206_3216Metric_Pad1.42x1.75mm_HandSolder
D6: FM2 - Amber LED; D_1206_3216Metric_Pad1.42x1.75mm_HandSolder
D7: IND- Amber LED; D_1206_3216Metric_Pad1.42x1.75mm_HandSolder
D8: RDY - Green LED; D_1206_3216Metric_Pad1.42x1.75mm_HandSolder
D9: FAIL - Amber LED; D_1206_3216Metric_Pad1.42x1.75mm_HandSolder
D10: MCDU MENU - WHITE LED; D_1206_3216Metric_Pad1.42x1.75mm_HandSolder
D11: FM - White LED; D_1206_3216Metric_Pad1.42x1.75mm_HandSolder
J1, J2, J3, J4, J6, J7, J8, J9: Conn_02x01; TerminalBlock_bornier-2_P5.08mm
J5: Conn_02x01; PinHeader_2x20_P2.54mm_Vertical
R1, R2, R3, R4, R37, R38, R39, R40, R41, R42, R43: 470R; R_1206_3216Metric_Pad1.30x1.75mm_HandSolder
R5, R6, R7, R8, R9: 10k; R_1206_3216Metric_Pad1.30x1.75mm_HandSolder
R10, R11, R12: 2.2k; R_1206_3216Metric_Pad1.30x1.75mm_HandSolder
R13, R14, R15, R16, R17, R18, R19, R20, R21, R22, R23, R24, R25, R26, R27, R28, R29, R30, R31, R32, R33, R34, R35, R44, R47: 220R; R_1210_3225Metric_Pad1.30x2.65mm_HandSolder
R36: 470R; R_1210_3225Metric_Pad1.30x2.65mm_HandSolder
R45: 22.0K; R_1210_3225Metric_Pad1.30x2.65mm_HandSolder
R46: 10.0K; R_1210_3225Metric_Pad1.30x2.65mm_HandSolder
SW1, SW2, SW3, SW4, SW5, SW6, SW7, SW8, SW9, SW10, SW11, SW12, SW13, SW14, SW15, SW16, SW17, SW18, SW19, SW20, SW21, SW22, SW23, SW24, SW25, SW26, SW27, SW28, SW29, SW30, SW31, SW32, SW33, SW34, SW35, SW36, SW37, SW38, SW39, SW40, SW41, SW42, SW43, SW44, SW45, SW46, SW47, SW48, SW49, SW50, SW51, SW52, SW53, SW54, SW55, SW56, SW57, SW58, SW59, SW60, SW61, SW62, SW63, SW64, SW65, SW66, SW67, SW68, SW69, SW70, SW71, SW72, SW73, SW74: TLL-6A; TACTILE_LED_TH
SW100: SW_MEC_5E; SW_TH_Tactile_Omron_B3F-10xx
U1, U2, U3, U4, U5: MCP23017_SO; SOIC-28W_7.5x17.9mm_P1.27mm

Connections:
+5V: C1.1, C2.1, C3.1, C4.1, C5.1, D1.2 (A), J1.1, J2.1, J5.2 (5V), J5.4 (5V), R5.1, R6.1, R7.1, R8.1, R9.1, R10.2, R11.2, R12.2, U1.9 (VDD), U2.9 (VDD), U2.15 (A0), U3.9 (VDD), U3.16 (A1), U4.9 (VDD), U4.15 (A0), U4.16 (A1), U5.9 (VDD), U5.17 (A2)
+12V: J3.1, J4.1, SW1.3, SW4.3, SW7.3, SW10.3, SW13.3, SW16.3, SW19.3, SW22.3, SW25.3, SW28.3, SW31.3, SW34.3, SW37.3, SW40.3, SW43.3, SW46.3, SW49.3, SW52.3, SW55.3, SW58.3, SW61.3, SW64.3, SW67.3, SW70.3, SW71.3, SW73.3
/BUS0-0: SW1.1, U1.21 (GPA0)
/BUS0-1: SW2.1, U1.22 (GPA1)
/BUS0-2: SW3.1, U1.23 (GPA2)
/BUS0-3: SW4.1, U1.24 (GPA3)
/BUS0-4: SW5.1, U1.25 (GPA4)
/BUS0-5: SW6.1, U1.26 (GPA5)
/BUS0-6: SW7.1, U1.27 (GPA6)
/BUS0-7: SW8.1, U1.28 (GPA7)
/BUS0-8: SW9.1, U1.1 (GPB0)
/BUS0-9: SW10.1, U1.2 (GPB1)
/BUS0-10: SW11.1, U1.3 (GPB2)
/BUS0-11: SW12.1, U1.4 (GPB3)
/BUS0-12: SW13.1, U1.5 (GPB4)
/BUS0-13: SW14.1, U1.6 (GPB5)
/BUS0-14: SW15.1, U1.7 (GPB6)
/BUS0-15: SW16.1, U1.8 (GPB7)
/BUS1-0: SW17.1, U2.21 (GPA0)
/BUS1-1: SW18.1, U2.22 (GPA1)
/BUS1-2: SW19.1, U2.23 (GPA2)
/BUS1-3: SW20.1, U2.24 (GPA3)
/BUS1-4: SW21.1, U2.25 (GPA4)
/BUS1-5: SW22.1, U2.26 (GPA5)
/BUS1-6: SW23.1, U2.27 (GPA6)
/BUS1-7: SW24.1, U2.28 (GPA7)
/BUS1-8: SW25.1, U2.1 (GPB0)
/BUS1-9: SW26.1, U2.2 (GPB1)
/BUS1-10: SW27.1, U2.3 (GPB2)
/BUS1-11: SW28.1, U2.4 (GPB3)
/BUS1-12: SW29.1, U2.5 (GPB4)
/BUS1-13: SW30.1, U2.6 (GPB5)
/BUS1-14: SW31.1, U2.7 (GPB6)
/BUS1-15: SW32.1, U2.8 (GPB7)
/BUS2-0: SW33.1, U3.21 (GPA0)
/BUS2-1: SW34.1, U3.22 (GPA1)
/BUS2-2: SW35.1, U3.23 (GPA2)
/BUS2-3: SW36.1, U3.24 (GPA3)
/BUS2-4: SW37.1, U3.25 (GPA4)
/BUS2-5: SW38.1, U3.26 (GPA5)
/BUS2-6: SW39.1, U3.27 (GPA6)
/BUS2-7: SW40.1, U3.28 (GPA7)
/BUS2-8: SW41.1, U3.1 (GPB0)
/BUS2-9: SW42.1, U3.2 (GPB1)
/BUS2-10: SW43.1, U3.3 (GPB2)
/BUS2-11: SW44.1, U3.4 (GPB3)
/BUS2-12: SW45.1, U3.5 (GPB4)
/BUS2-13: SW46.1, U3.6 (GPB5)
/BUS2-14: SW47.1, U3.7 (GPB6)
/BUS2-15: SW48.1, U3.8 (GPB7)
/BUS3-0: SW49.1, U4.21 (GPA0)
/BUS3-1: SW50.1, U4.22 (GPA1)
/BUS3-2: SW51.1, U4.23 (GPA2)
/BUS3-3: SW52.1, U4.24 (GPA3)
/BUS3-4: SW53.1, U4.25 (GPA4)
/BUS3-5: SW54.1, U4.26 (GPA5)
/BUS3-6: SW55.1, U4.27 (GPA6)
/BUS3-7: SW56.1, U4.28 (GPA7)
/BUS3-8: SW57.1, U4.1 (GPB0)
/BUS3-9: SW58.1, U4.2 (GPB1)
/BUS3-10: SW59.1, U4.3 (GPB2)
/BUS3-11: SW60.1, U4.4 (GPB3)
/BUS3-12: SW61.1, U4.5 (GPB4)
/BUS3-13: SW62.1, U4.6 (GPB5)
/BUS3-14: SW63.1, U4.7 (GPB6)
/BUS3-15: SW64.1, U4.8 (GPB7)
/BUS4-0: SW65.1, U5.21 (GPA0)
/BUS4-1: SW66.1, U5.22 (GPA1)
/BUS4-2: SW67.1, U5.23 (GPA2)
/BUS4-3: SW68.1, U5.24 (GPA3)
/BUS4-4: SW69.1, U5.25 (GPA4)
/BUS4-5: SW70.1, U5.26 (GPA5)
/BUS4-6: D5.2 (A), U5.27 (GPA6)
/BUS4-7: D6.2 (A), U5.28 (GPA7)
/BUS4-8: D7.2 (A), U5.1 (GPB0)
/BUS4-9: D8.2 (A), U5.2 (GPB1)
/BUS4-10: D9.2 (A), U5.3 (GPB2)
/BUS4-11: D10.2 (A), U5.4 (GPB3)
/BUS4-12: D11.2 (A), U5.5 (GPB4)
BUSES_RESET: J5.12 (GPIO18/PWM0), U1.18 (~RESET~), U2.18 (~RESET~), U3.18 (~RESET~), U4.18 (~RESET~), U5.18 (~RESET~)
FAULT_LED: D3.2 (A), J5.29 (GCLK1/GPIO5)
GENERAL_LED: D2.2 (A), J5.31 (GCLK2/GPIO6)
GND: C1.2, C2.2, C3.2, C4.2, C5.2, J1.2, J2.2, J3.2, J4.2, J5.6 (GND), R1.2, R2.2, R3.2, R4.2, R13.2, R14.2, R15.2, R16.2, R17.2, R18.2, R19.2, R20.2, R21.2, R22.2, R23.2, R24.2, R25.2, R26.2, R27.2, R28.2, R29.2, R30.2, R31.2, R32.2, R33.2, R34.2, R35.2, R36.2, R37.2, R38.2, R39.2, R40.2, R41.2, R42.2, R43.2, R44.2, R47.2, SW1.2, SW2.2, SW3.2, SW4.2, SW5.2, SW6.2, SW7.2, SW8.2, SW9.2, SW10.2, SW11.2, SW12.2, SW13.2, SW14.2, SW15.2, SW16.2, SW17.2, SW18.2, SW19.2, SW20.2, SW21.2, SW22.2, SW23.2, SW24.2, SW25.2, SW26.2, SW27.2, SW28.2, SW29.2, SW30.2, SW31.2, SW32.2, SW33.2, SW34.2, SW35.2, SW36.2, SW37.2, SW38.2, SW39.2, SW40.2, SW41.2, SW42.2, SW43.2, SW44.2, SW45.2, SW46.2, SW47.2, SW48.2, SW49.2, SW50.2, SW51.2, SW52.2, SW53.2, SW54.2, SW55.2, SW56.2, SW57.2, SW58.2, SW59.2, SW60.2, SW61.2, SW62.2, SW63.2, SW64.2, SW65.2, SW66.2, SW67.2, SW68.2, SW69.2, SW70.2, SW100.1, SW100.2, U1.10 (VSS), U1.15 (A0), U1.16 (A1), U1.17 (A2), U2.10 (VSS), U2.16 (A1), U2.17 (A2), U3.10 (VSS), U3.15 (A0), U3.17 (A2), U4.10 (VSS), U4.17 (A2), U5.10 (VSS), U5.15 (A0), U5.16 (A1)
INT_BUS_0: J5.36 (GPIO16), R5.2, U1.20 (INTA)
INT_BUS_1: J5.11 (GPIO17), R6.2, U2.20 (INTA)
INT_BUS_2: J5.15 (GPIO22), R7.2, U3.20 (INTA)
INT_BUS_3: J5.16 (GPIO23), R8.2, U4.20 (INTA)
INT_BUS_4: J5.18 (GPIO24), R9.2, U5.20 (INTA)
unnamed: D1.1 (K), R1.1
unnamed: D2.1 (K), R2.1
unnamed: D3.1 (K), R3.1
unnamed: D4.1 (K), R4.1
unnamed: D5.1 (K), R37.1
unnamed: D6.1 (K), R38.1
unnamed: D7.1 (K), R39.1
unnamed: D8.1 (K), R40.1
unnamed: D9.1 (K), R41.1
unnamed: D10.1 (K), R42.1
unnamed: D11.1 (K), R43.1
unnamed: J6.1, SW71.1
unnamed: J6.2, SW71.2
unnamed: J7.1, SW72.1
unnamed: J7.2, SW72.2
unnamed: J8.1, SW73.1
unnamed: J8.2, R45.2
unnamed: J9.1, SW74.1
unnamed: J9.2, R46.2
unnamed: R13.1, SW3.4
unnamed: R14.1, SW6.4
unnamed: R15.1, SW9.4
unnamed: R16.1, SW12.4
unnamed: R17.1, SW15.4
unnamed: R18.1, SW18.4
unnamed: R19.1, SW21.4
unnamed: R20.1, SW24.4
unnamed: R21.1, SW27.4
unnamed: R22.1, SW30.4
unnamed: R23.1, SW33.4
unnamed: R24.1, SW36.4
unnamed: R25.1, SW39.4
unnamed: R26.1, SW42.4
unnamed: R27.1, SW45.4
unnamed: R28.1, SW48.4
unnamed: R29.1, SW51.4
unnamed: R30.1, SW54.4
unnamed: R31.1, SW57.4
unnamed: R32.1, SW60.4
unnamed: R33.1, SW63.4
unnamed: R34.1, SW66.4
unnamed: R35.1, SW69.4
unnamed: R36.1, SW70.4
unnamed: R44.1, SW72.4
unnamed: R45.1, SW73.2
unnamed: R46.1, SW74.2
unnamed: R47.1, SW74.4
unnamed: SW1.4, SW2.3
unnamed: SW2.4, SW3.3
unnamed: SW4.4, SW5.3
unnamed: SW5.4, SW6.3
unnamed: SW7.4, SW8.3
unnamed: SW8.4, SW9.3
unnamed: SW10.4, SW11.3
unnamed: SW11.4, SW12.3
unnamed: SW13.4, SW14.3
unnamed: SW14.4, SW15.3
unnamed: SW16.4, SW17.3
unnamed: SW17.4, SW18.3
unnamed: SW19.4, SW20.3
unnamed: SW20.4, SW21.3
unnamed: SW22.4, SW23.3
unnamed: SW23.4, SW24.3
unnamed: SW25.4, SW26.3
unnamed: SW26.4, SW27.3
unnamed: SW28.4, SW29.3
unnamed: SW29.4, SW30.3
unnamed: SW31.4, SW32.3
unnamed: SW32.4, SW33.3
unnamed: SW34.4, SW35.3
unnamed: SW35.4, SW36.3
unnamed: SW37.4, SW38.3
unnamed: SW38.4, SW39.3
unnamed: SW40.4, SW41.3
unnamed: SW41.4, SW42.3
unnamed: SW43.4, SW44.3
unnamed: SW44.4, SW45.3
unnamed: SW46.4, SW47.3
unnamed: SW47.4, SW48.3
unnamed: SW49.4, SW50.3
unnamed: SW50.4, SW51.3
unnamed: SW52.4, SW53.3
unnamed: SW53.4, SW54.3
unnamed: SW55.4, SW56.3
unnamed: SW56.4, SW57.3
unnamed: SW58.4, SW59.3
unnamed: SW59.4, SW60.3
unnamed: SW61.4, SW62.3
unnamed: SW62.4, SW63.3
unnamed: SW64.4, SW65.3
unnamed: SW65.4, SW66.3
unnamed: SW67.4, SW68.3
unnamed: SW68.4, SW69.3
unnamed: SW71.4, SW72.3
unnamed: SW73.4, SW74.3
RESET_SWITCH: J5.26 (~CE1~/GPIO7), R12.1, SW100.3 (K), SW100.4 (A)
SCL: J5.5 (SCL/GPIO3), R11.1, U1.12 (SCK), U2.12 (SCK), U3.12 (SCK), U4.12 (SCK), U5.12 (SCK)
SDA: J5.3 (SDA/GPIO2), R10.1, U1.13 (SDA), U2.13 (SDA), U3.13 (SDA), U4.13 (SDA), U5.13 (SDA)
SIGNAL_LED: D4.2 (A), J5.7 (GCLK0/GPIO4)

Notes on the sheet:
I2C Pullups
LED Indicators
PI ZERO CONNECTION
MCP Extenders
Decoupling Capacitors for ICs
Interrupts Pull-up Resistors
Supply Terminal Blocks 5V & 12V Variable for Backlight
Reset Switch
MCDU LEFT SIDE KEYS
MCDU RIGHT SIDE KEYS
MCDU MENU KEYS
MCDU NUMERIC KEYS
MCDU ALPHABET KEYS
Annunciators Lights

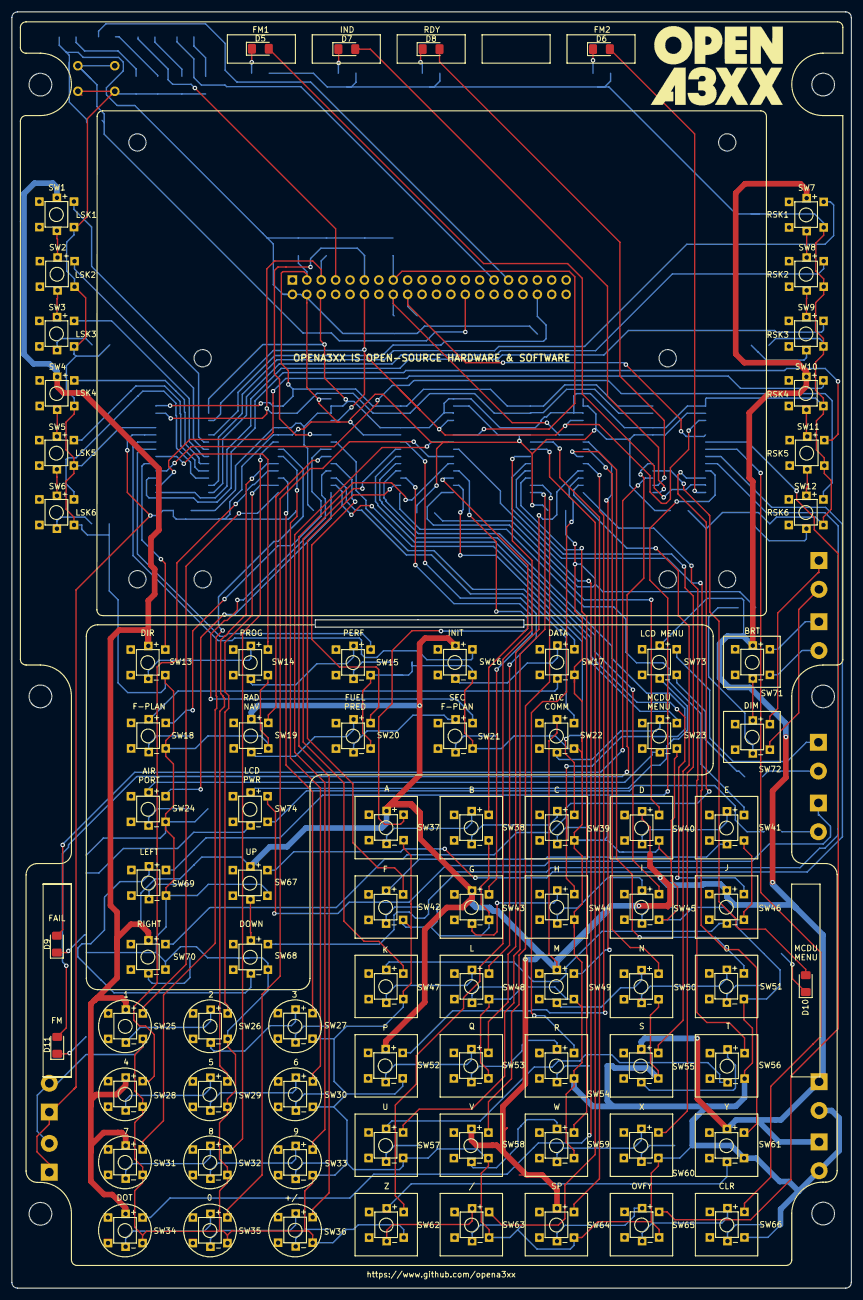
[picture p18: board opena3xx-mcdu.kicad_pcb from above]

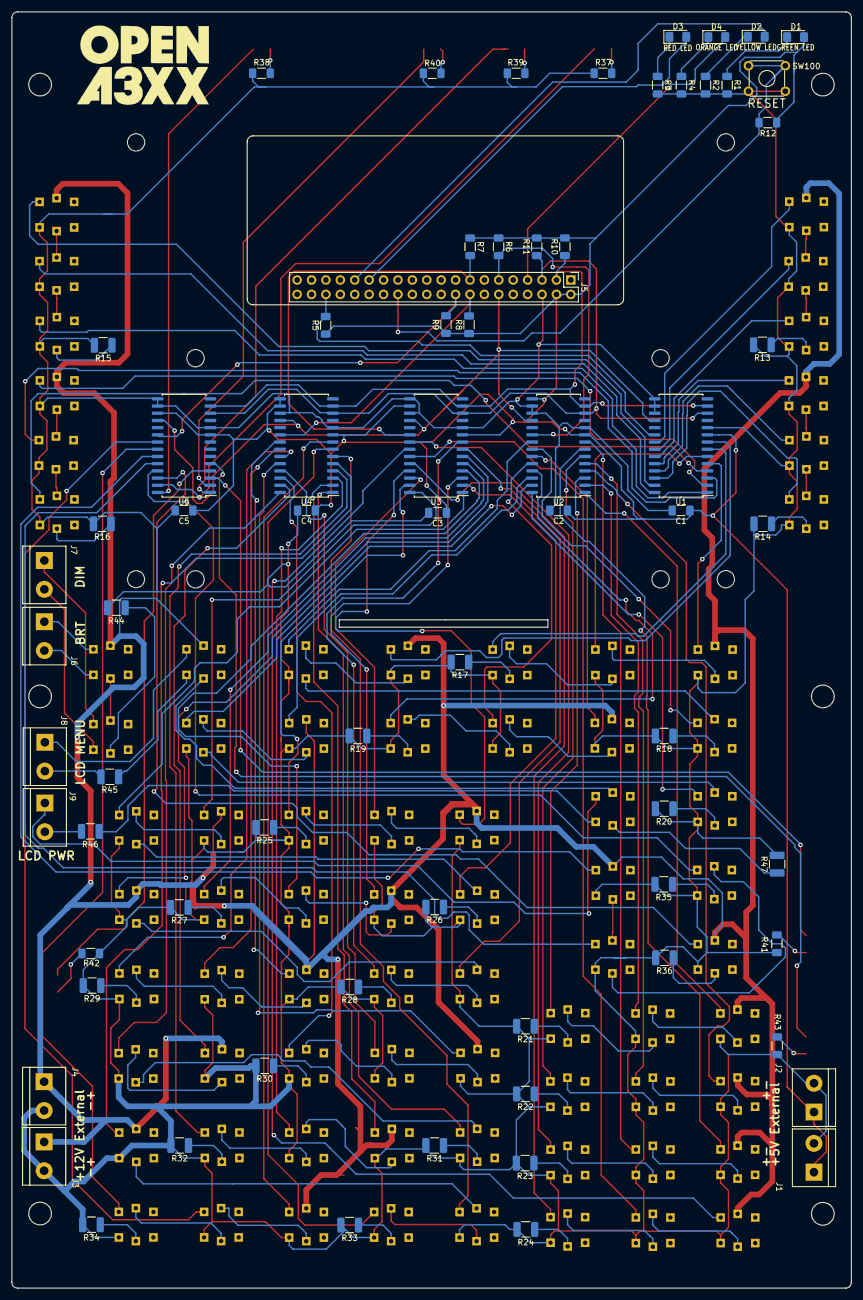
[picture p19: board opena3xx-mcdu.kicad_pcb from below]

Board: 2 copper layers, 148.0 x 225.0 mm, 152 parts (71 on the bottom side), 187 nets.

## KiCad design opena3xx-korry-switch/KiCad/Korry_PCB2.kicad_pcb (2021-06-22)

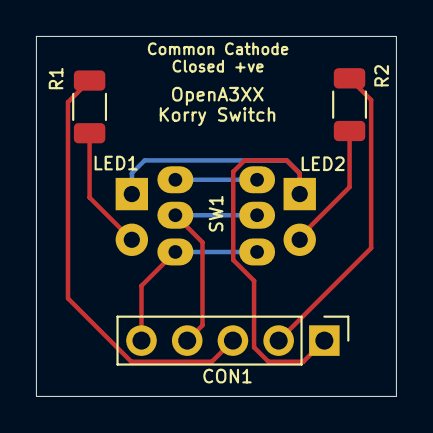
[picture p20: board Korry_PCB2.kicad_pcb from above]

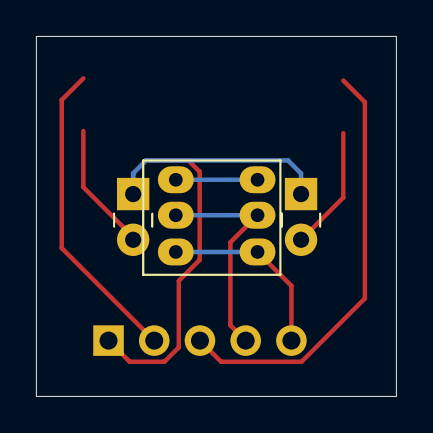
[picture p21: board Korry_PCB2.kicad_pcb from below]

Board: 2 copper layers, 20.0 x 20.0 mm, 6 parts (3 on the bottom side), 7 nets.

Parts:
CON1: Conn_01x05_MountingPin; PinHeader_1x05_P2.54mm_Vertical
LED1, LED2: LED; LED_Rectangular_W3.0mm_H2.0mm
R1, R2: 270; R_1206_3216Metric
SW1: S775-1; 6pin_Push_Button_Switch

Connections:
unnamed: CON1.1, LED1.1, LED2.1
unnamed: LED1.2, R1.1
unnamed: LED2.2, R2.1
unnamed: CON1.2, R2.2
unnamed: CON1.3, R1.2
unnamed: CON1.4, SW1.2
unnamed: CON1.5, SW1.1

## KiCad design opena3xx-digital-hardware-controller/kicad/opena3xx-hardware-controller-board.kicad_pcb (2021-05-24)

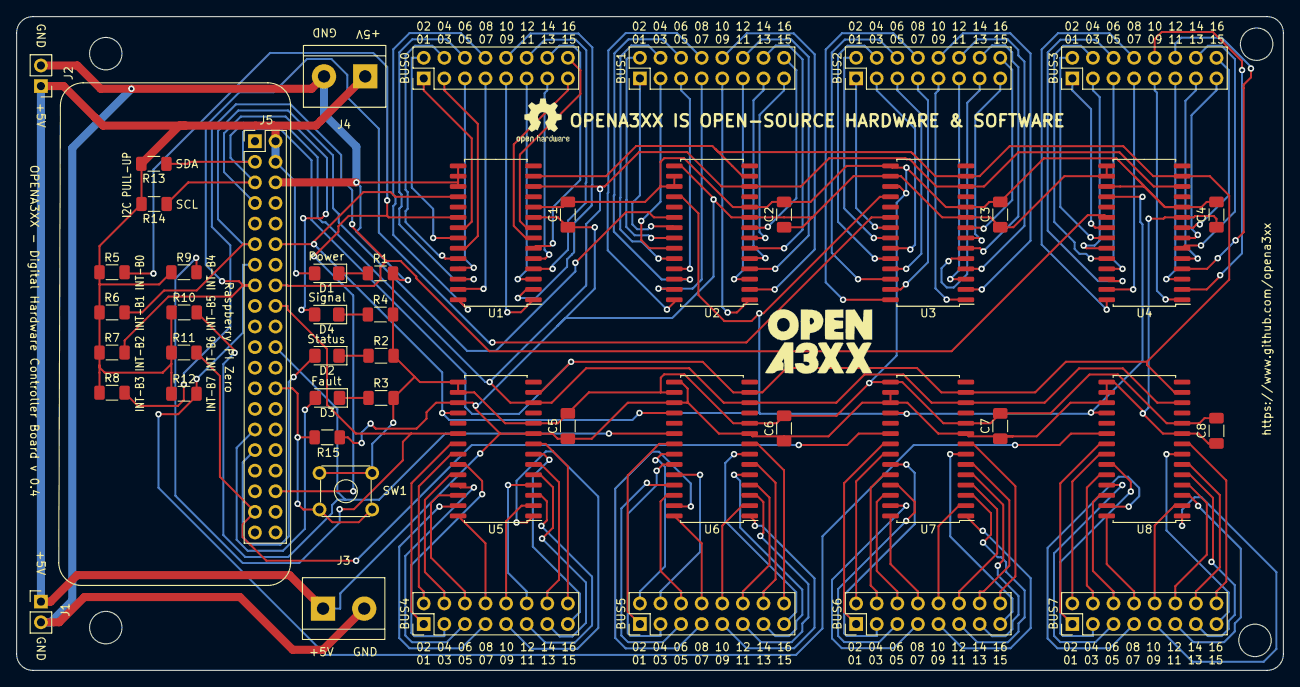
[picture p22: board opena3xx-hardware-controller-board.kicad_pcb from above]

Board: 2 copper layers, 156.3 x 80.6 mm, 49 parts (0 on the bottom side), 149 nets.

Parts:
BUS0, BUS1, BUS2, BUS3, BUS4, BUS5, BUS6, BUS7: Conn_02x08_Counter_Clockwise; PinHeader_2x08_P2.54mm_Vertical
C1, C2, C3, C4, C5, C6, C7, C8: 100n; C_1206_3216Metric_Pad1.33x1.80mm_HandSolder
D1: GREEN LED; D_1206_3216Metric_Pad1.42x1.75mm_HandSolder
D2: YELLOW LED; D_1206_3216Metric_Pad1.42x1.75mm_HandSolder
D3: RED LED; D_1206_3216Metric_Pad1.42x1.75mm_HandSolder
D4: ORANGE LED; D_1206_3216Metric_Pad1.42x1.75mm_HandSolder
J1, J2: Conn_02x01; PinHeader_1x02_P2.54mm_Vertical
J3, J4: Conn_02x01; TerminalBlock_bornier-2_P5.08mm
J5: Raspberry_Pi_Zero; PinHeader_2x20_P2.54mm_Vertical
R1, R2, R3, R4: 470R; R_1206_3216Metric_Pad1.30x1.75mm_HandSolder
R5, R6, R7, R8, R9, R10, R11, R12: 10k; R_1206_3216Metric_Pad1.30x1.75mm_HandSolder
R13, R14, R15: 2.2k; R_1206_3216Metric_Pad1.30x1.75mm_HandSolder
SW1: SW_MEC_5E; SW_TH_Tactile_Omron_B3F-10xx
U1, U2, U3, U4, U5, U6, U7, U8: MCP23017_SO; SOIC-28W_7.5x17.9mm_P1.27mm

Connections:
+5V: C1.1, C2.1, C3.1, C4.1, C5.1, C6.1, C7.1, C8.1, D1.2, J1.1, J2.1, J3.1, J4.1, J5.2, J5.4, R5.1, R6.1, R7.1, R8.1, R9.1, R10.1, R11.1, R12.1, R13.2, R14.2, R15.2, U1.9, U2.9, U2.15, U3.9, U3.16, U4.9, U4.15, U4.16, U5.9, U5.17, U6.9, U6.15, U6.17, U7.9, U7.16, U7.17, U8.9, U8.15, U8.16, U8.17
/BUS0-0: BUS0.1, U1.21
/BUS0-1: BUS0.2, U1.22
/BUS0-2: BUS0.3, U1.23
/BUS0-3: BUS0.4, U1.24
/BUS0-4: BUS0.5, U1.25
/BUS0-5: BUS0.6, U1.26
/BUS0-6: BUS0.7, U1.27
/BUS0-7: BUS0.8, U1.28
/BUS0-8: BUS0.9, U1.1
/BUS0-9: BUS0.10, U1.2
/BUS0-10: BUS0.11, U1.3
/BUS0-11: BUS0.12, U1.4
/BUS0-12: BUS0.13, U1.5
/BUS0-13: BUS0.14, U1.6
/BUS0-14: BUS0.15, U1.7
/BUS0-15: BUS0.16, U1.8
/BUS1-0: BUS1.1, U2.21
/BUS1-1: BUS1.2, U2.22
/BUS1-2: BUS1.3, U2.23
/BUS1-3: BUS1.4, U2.24
/BUS1-4: BUS1.5, U2.25
/BUS1-5: BUS1.6, U2.26
/BUS1-6: BUS1.7, U2.27
/BUS1-7: BUS1.8, U2.28
/BUS1-8: BUS1.9, U2.1
/BUS1-9: BUS1.10, U2.2
/BUS1-10: BUS1.11, U2.3
/BUS1-11: BUS1.12, U2.4
/BUS1-12: BUS1.13, U2.5
/BUS1-13: BUS1.14, U2.6
/BUS1-14: BUS1.15, U2.7
/BUS1-15: BUS1.16, U2.8
/BUS2-0: BUS2.1, U3.21
/BUS2-1: BUS2.2, U3.22
/BUS2-2: BUS2.3, U3.23
/BUS2-3: BUS2.4, U3.24
/BUS2-4: BUS2.5, U3.25
/BUS2-5: BUS2.6, U3.26
/BUS2-6: BUS2.7, U3.27
/BUS2-7: BUS2.8, U3.28
/BUS2-8: BUS2.9, U3.1
/BUS2-9: BUS2.10, U3.2
/BUS2-10: BUS2.11, U3.3
/BUS2-11: BUS2.12, U3.4
/BUS2-12: BUS2.13, U3.5
/BUS2-13: BUS2.14, U3.6
/BUS2-14: BUS2.15, U3.7
/BUS2-15: BUS2.16, U3.8
/BUS3-0: BUS3.1, U4.21
/BUS3-1: BUS3.2, U4.22
/BUS3-2: BUS3.3, U4.23
/BUS3-3: BUS3.4, U4.24
/BUS3-4: BUS3.5, U4.25
/BUS3-5: BUS3.6, U4.26
/BUS3-6: BUS3.7, U4.27
/BUS3-7: BUS3.8, U4.28
/BUS3-8: BUS3.9, U4.1
/BUS3-9: BUS3.10, U4.2
/BUS3-10: BUS3.11, U4.3
/BUS3-11: BUS3.12, U4.4
/BUS3-12: BUS3.13, U4.5
/BUS3-13: BUS3.14, U4.6
/BUS3-14: BUS3.15, U4.7
/BUS3-15: BUS3.16, U4.8
/BUS4-0: BUS4.1, U5.21
/BUS4-1: BUS4.2, U5.22
/BUS4-2: BUS4.3, U5.23
/BUS4-3: BUS4.4, U5.24
/BUS4-4: BUS4.5, U5.25
/BUS4-5: BUS4.6, U5.26
/BUS4-6: BUS4.7, U5.27
/BUS4-7: BUS4.8, U5.28
/BUS4-8: BUS4.9, U5.1
/BUS4-9: BUS4.10, U5.2
/BUS4-10: BUS4.11, U5.3
/BUS4-11: BUS4.12, U5.4
/BUS4-12: BUS4.13, U5.5
/BUS4-13: BUS4.14, U5.6
/BUS4-14: BUS4.15, U5.7
/BUS4-15: BUS4.16, U5.8
/BUS5-0: BUS5.1, U6.21
/BUS5-1: BUS5.2, U6.22
/BUS5-2: BUS5.3, U6.23
/BUS5-3: BUS5.4, U6.24
/BUS5-4: BUS5.5, U6.25
/BUS5-5: BUS5.6, U6.26
/BUS5-6: BUS5.7, U6.27
/BUS5-7: BUS5.8, U6.28
/BUS5-8: BUS5.9, U6.1
/BUS5-9: BUS5.10, U6.2
/BUS5-10: BUS5.11, U6.3
/BUS5-11: BUS5.12, U6.4
/BUS5-12: BUS5.13, U6.5
/BUS5-13: BUS5.14, U6.6
/BUS5-14: BUS5.15, U6.7
/BUS5-15: BUS5.16, U6.8
/BUS6-0: BUS6.1, U7.21
/BUS6-1: BUS6.2, U7.22
/BUS6-2: BUS6.3, U7.23
/BUS6-3: BUS6.4, U7.24
/BUS6-4: BUS6.5, U7.25
/BUS6-5: BUS6.6, U7.26
/BUS6-6: BUS6.7, U7.27
/BUS6-7: BUS6.8, U7.28
/BUS6-8: BUS6.9, U7.1
/BUS6-9: BUS6.10, U7.2
/BUS6-10: BUS6.11, U7.3
/BUS6-11: BUS6.12, U7.4
/BUS6-12: BUS6.13, U7.5
/BUS6-13: BUS6.14, U7.6
/BUS6-14: BUS6.15, U7.7
/BUS6-15: BUS6.16, U7.8
/BUS7-0: BUS7.1, U8.21
/BUS7-1: BUS7.2, U8.22
/BUS7-2: BUS7.3, U8.23
/BUS7-3: BUS7.4, U8.24
/BUS7-4: BUS7.5, U8.25
/BUS7-5: BUS7.6, U8.26
/BUS7-6: BUS7.7, U8.27
/BUS7-7: BUS7.8, U8.28
/BUS7-8: BUS7.9, U8.1
/BUS7-9: BUS7.10, U8.2
/BUS7-10: BUS7.11, U8.3
/BUS7-11: BUS7.12, U8.4
/BUS7-12: BUS7.13, U8.5
/BUS7-13: BUS7.14, U8.6
/BUS7-14: BUS7.15, U8.7
/BUS7-15: BUS7.16, U8.8
BUSES_RESET: J5.12, U1.18, U2.18, U3.18, U4.18, U5.18, U6.18, U7.18, U8.18
FAULT_LED: D3.2, J5.29
GENERAL_LED: D2.2, J5.31
GND: C1.2, C2.2, C3.2, C4.2, C5.2, C6.2, C7.2, C8.2, J1.2, J2.2, J3.2, J4.2, J5.6, R1.2, R2.2, R3.2, R4.2, SW1.1, SW1.2, U1.10, U1.15, U1.16, U1.17, U2.10, U2.16, U2.17, U3.10, U3.15, U3.17, U4.10, U4.17, U5.10, U5.15, U5.16, U6.10, U6.16, U7.10, U7.15, U8.10
INT_BUS_0: J5.36, R5.2, U1.20
INT_BUS_1: J5.11, R6.2, U2.20
INT_BUS_2: J5.15, R7.2, U3.20
INT_BUS_3: J5.16, R8.2, U4.20
INT_BUS_4: J5.18, R9.2, U5.20
INT_BUS_5: J5.22, R10.2, U6.20
INT_BUS_6: J5.37, R11.2, U7.20
INT_BUS_7: J5.13, R12.2, U8.20
MESSAGING_LED: D4.2, J5.7
unnamed: D1.1, R1.1
unnamed: D2.1, R2.1
unnamed: D3.1, R3.1
unnamed: D4.1, R4.1
RESET_SWITCH: J5.26, R15.1, SW1.3, SW1.4
SCL: J5.5, R14.1, U1.12, U2.12, U3.12, U4.12, U5.12, U6.12, U7.12, U8.12
SDA: J5.3, R13.1, U1.13, U2.13, U3.13, U4.13, U5.13, U6.13, U7.13, U8.13

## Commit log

2021-01-28 Added MCDU Schematic WIP
    [mcdu.DSN]
2021-03-31 Updated Schematic
    [mcdu.DSN]
2021-04-10 Started OpenA3XX Hardware Controller
    [opena3xx-digital-hardware-controller.DSN, opena3xx-digital-hardware-controller.SDF]
2021-04-10 Continuation of Digital Hardware Controller Schematic + PCB
    [opena3xx-digital-hardware-controller.DSN, opena3xx-digital-hardware-controller.SDF]
2021-04-11 Hadware Controller Schematic v0.1 - Done
    [opena3xx-digital-hardware-controller.DSN, opena3xx-digital-hardware-controller.SDF]
2021-04-11 Finalising PCB v 0.1
    [opena3xx-digital-hardware-controller.SDF]
2021-04-11 Fixed DIL16 Connector (Was Flipped) Routed Manually BUS4
2021-04-12 Minor PCB IMprovements Fixed SDA/SCL Lines (Swapped in Schematic)
    [opena3xx-digital-hardware-controller.DSN, opena3xx-digital-hardware-controller.SDF]
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2021-04-17 Added 3d models for discrete components
    [1212D.dwg]
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2021-04-18 Fixing issue with switches pinouts/leds - Rerouting
2021-04-18 Fixes Completed. PCB Routed: Manual verification tests PENDING - MCDU
2021-04-19 Added OpenA3XX IO Terminal Block Board
    [opena3xx-digital-hardware-controller.DSN, opena3xx-digital-hardware-controller.SDF]
2021-04-20 started v0.2 - implementing fixes after 0.1 prototype result
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2021-05-01 Implementing v0.3 DHCB PCB (imporvements and minor fixes over v0.2)
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2021-05-09 Adding digtal hardware controller v 0.4 in kicad
    [opena3xx-hardware-controller-board-B_Cu.gbr, opena3xx-hardware-controller-board-B_Mask.gbr, opena3xx-hardware-controller-board-B_Paste.gbr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]
2021-05-09 DHCB Gerber V0.4
    [opena3xx-hardware-controller-board-B_Cu.gbr, opena3xx-hardware-controller-board-B_Mask.gbr, opena3xx-hardware-controller-board-B_Paste.gbr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]
2021-05-10 Changed text from Messaging to Signal in Top Mask
    [opena3xx-hardware-controller-board.kicad_pcb]
2021-05-11 Created mcdu project in Kicad
    [opena3xx-hardware-controller-board.kicad_pcb, opena3xx-mcdu.kicad_pcb, opena3xx-mcdu.sch]
2021-05-15 WIP Schematic & PCB for the MCDU Added custom Kicad Packages for the Tactile Switchs (LED EMBEDDED)
    [opena3xx-hardware-controller-board.kicad_pcb, opena3xx-mcdu.kicad_pcb, opena3xx-mcdu.sch]
2021-05-15 Schematic Updates - MCDU
    [opena3xx-mcdu.sch]
2021-05-15 Updated MCDU Schematic
    [opena3xx-mcdu.sch]
2021-05-15 MCDU Updates
    [opena3xx-mcdu.kicad_pcb, opena3xx-mcdu.sch]
2021-05-16 Updates MCDU Schematic
    [opena3xx-mcdu.sch]
2021-05-16 Completed MCDU Schematic v0.1
    [opena3xx-mcdu.kicad_pcb, opena3xx-mcdu.sch]
2021-05-22 Added readme file for DHC Board
    [opena3xx-hardware-controller-board.csv]
2021-05-22 Fixed Silkscreen for the BUS connectors - from 1/16 to 0/15
    [opena3xx-hardware-controller-board.kicad_pcb]
2021-05-23 Updated MCDU PCB Layout for Tactile Switches completed.
    [opena3xx-mcdu.kicad_pcb]
2021-05-23 WIP PCB Layout process for MCDU - ICs and connectors
    [opena3xx-mcdu.kicad_pcb, opena3xx-mcdu.sch]
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2021-05-24 Continuation of MCDU PCB v0.1
    [opena3xx-mcdu.kicad_pcb]
2021-05-25 Updated PCB MCDU v0.1
    [opena3xx-hardware-controller-board.kicad_pcb, opena3xx-mcdu.dsn, opena3xx-mcdu.kicad_pcb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]
2021-05-25 Finalised Layour for MCDU PCB v 0.1
    [opena3xx-mcdu.dsn, opena3xx-mcdu.kicad_pcb, opena3xx-mcdu.sch]
2021-05-29 Fixing PCB dimensions for the MCDU
    [opena3xx-mcdu.kicad_pcb]
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2021-05-29 PCB MCDU changes
    [opena3xx-mcdu.kicad_pcb]
2021-05-30 Minor changes MCDU PCB
    [opena3xx-mcdu.kicad_pcb]
2021-05-30 Adding all buttons/led marking as Front Silk
    [opena3xx-mcdu.kicad_pcb]
2021-05-30 Finished all markings and moved also component reference to the right position.
    [opena3xx-mcdu.kicad_pcb]
2021-05-30 Minor Fix
    [opena3xx-mcdu.kicad_pcb]
2021-06-02 Fixed MCDU PCB with updated LSK RSK button Layout & Moved resistors to bottom of the PCB
    [opena3xx-mcdu.kicad_pcb]
2021-06-02 Removed vertical line of the screen (extra)
    [opena3xx-mcdu.kicad_pcb]
2021-06-10 Updated PCB - Latest updates for Back and Front Panel Design
    [opena3xx-mcdu.kicad_pcb]
2021-06-10 Added Libs + MCDU fixes + Added LCD Menu Tactile Switch
    [opena3xx-mcdu.kicad_pcb, opena3xx-mcdu.sch]
2021-06-12 Updates MCDU PCB
    [opena3xx-mcdu.kicad_pcb, opena3xx-mcdu.sch]
2021-06-13 Added tactile 3d model MCDU
    [opena3xx-mcdu.kicad_pcb]
2021-06-13 Fixed LED Markings + STP File Updated
    [opena3xx-mcdu.kicad_pcb]
2021-06-14 Adding MCDU STL (PCB)
    Adding MCDU STL (PCB)
    [opena3xx-mcdu.kicad_pcb]
2021-06-15 Adding @Kavster89 LCD Driver Board holes.
    Adding @Kavster89 LCD Driver Board holes.
    [opena3xx-mcdu.kicad_pcb]
2021-06-15 MCDU Improvements Markings + Added Tactile for LCD Power + LED funcational names
    MCDU Improvements Markings + Added Tactile for LCD Power + LED funcational names
    [opena3xx-mcdu.kicad_pcb, opena3xx-mcdu.sch]
2021-06-15 Slight modification to lcd driver board alignment
    [opena3xx-mcdu.kicad_pcb]
2021-06-17 PCB MCDU UPDATES
    [opena3xx-mcdu-B_Cu.gbr, opena3xx-mcdu-B_Mask.gbr, opena3xx-mcdu-B_Paste.gbr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]
2021-06-17 Update LCD Driver Board Screws and Slot
    [opena3xx-mcdu.kicad_pcb]
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2021-06-19 Updating tracks and cleanup for MCDU
    [opena3xx-mcdu.kicad_pcb]
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2021-06-20 WIP LED Backlight Widining
    [opena3xx-mcdu.kicad_pcb]
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2021-06-22 Korry Switch Added
    Added the KiCad directory for the Korry switch.
    [BOM.xlsx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]
2021-07-01 Crating OpenA3XX Terminal Block PCB
    [opena3xx-io-terminal-block.kicad_pcb, opena3xx-io-terminal-block.sch, opena3xx-mcdu.kicad_pcb]
2022-01-05 PCB Update
    1) 12V connecters moved up slightly to allow room for mounting nut.
    2) Connected the LED's for the 'LCD MENU' and 'LCD PWR'.
    3) Added 2 resistors for the 'LCD MENU' and 'LCD PWR' to allow direct connection to the display PCB.
    [BOM.xlsx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]
2022-01-05 File restructure
    No change since last push.
    [opena3xx-mcdu-B_Adhes.gbr, opena3xx-mcdu-B_CrtYd.gbr, opena3xx-mcdu-B_Cu.gbl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]
2022-01-05 BOM & CPL
    BOM and CPL file created.
    They now also have the required part numbers for components.
    [BOM.xlsx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]
